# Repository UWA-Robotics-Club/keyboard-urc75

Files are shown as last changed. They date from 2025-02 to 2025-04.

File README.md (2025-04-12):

# Build your own Keyboard - URC 75



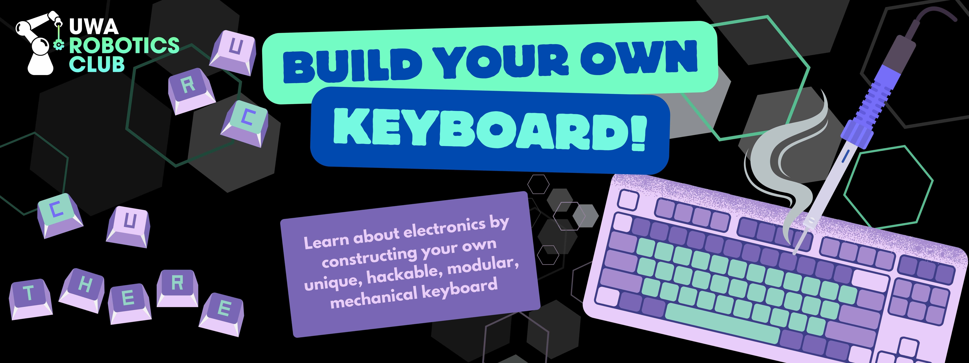
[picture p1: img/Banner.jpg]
Banner


## ⚠️ PSA: Resin printed cases have been identified as a consistant issue. New FDM 3D Printed Cases are currently being investigated, updates will be sent via email. Thank you :) ⚠️
[More about New Cases here](/FDM_Cases/FDM_Cases.md)

## 👀 Overview

This repository contains all files and instructions for the "Build Your Own Keyboard" project created by the UWA Robotics Club. 

This project was designed to be a beginners introduction to building electronics, as well as serving as an interesting product that UWA Robotics Club members have genuine use for, and can use day to day. 

**This project is fully opensource!**<br/>
All files to build your own "URC 75" from scratch, can be found in this respository, from the STEP files, to the schematics of the board, and the QMK firmware. 

# 🛠️ BUILD YOUR OWN! 

We have built a ready-to-go kit! Be sure to grab yours while there is still stock!
<div align = center>

[][Link_Kits]

[][Link_Build_Instructions]

Kit Image
</div>

## ✨ Features
Keyboard Image
- 75% Layout (82 keys)
- USB C Connector
- Hotswap Keyswitch Sockets
- Per Key RGB Lighting
- Acryllic Top Window to see Electronics
- Pudding Style Keycaps
- OLED Display (with Bongo Cat animation)
- Open-source design with complete build files
- Beginner-friendly assembly process
- Customizable firmware

## 🏁 Getting Started / Build Instructions
Full guide on how to assemble and solder your URC 75 Kit. 
- [**Full Guide**](/Build_Instructions/0_Build_Instructions.md)
- [Jump to Soldering](/Build_Instructions/2_Diodes.md)
- [Jump to Mechanical Assembly](/Build_Instructions/6_Heatset_and_Case_Assembly.md)
- [Jump to Firmware Installation](/Build_Instructions/9_Install_Firmware.md)

## 📣 Acknowledgments and Credits

### UWA Robotics Club 
- ⚡️ Prashan Wijesinghe  - Keyboard Electrical and Mechanical Design 
- 👷‍♂️ William Craig - Project Management, Marketing, Administration 
- 💰 UWA Robotics Club - Sponsoring the purchase of parts for kits
### External Credits
- All workshop participants who provided feedback
- QMK Firmware

## License

This project is licensed under the GPL2 

---

Created by UWA Robotics Club - https://uwarobotics.com.au/

[Link_kits]: /Kit_Info.md
[Buy a Kit]: https://img.shields.io/badge/Learn_more_about_our_Kits!-37a779?style=for-the-badge

[Link_Build_Instructions]: /Build_Instructions/0_Build_Instructions.md
[Build Instructions]: https://img.shields.io/badge/View_our_Build_instructions!-37a779?style=for-the-badge

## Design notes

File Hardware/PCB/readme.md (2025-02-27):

# DIY Keyboard Kit - PCB Design

## Repository Contents
This repository contains the following key files for the PCB design:

- **Schematic**: A complete schematic diagram of the keyboard PCB.
- **Bill of Materials (BOM)**: A list of all components required to assemble the PCB.
- **Gerber Files**: PCB manufacturing files, Use these if you want to order more PCB's
- **Altium Files**: A folder containing the neccsary files to edit the project in Altium designer

## Getting Started
To begin using these files for your PCB project:

1. **Download the Repository**: Clone or download the files to your local machine.
2. **Review the Schematic**: Understand the layout and connections.
3. **Order Components**: Use the BOM to gather all necessary parts.
4. **Verify Gerber Files**: Ensure files are correct using a viewer.
5. **Send Gerber Files for Manufacturing**: Choose a PCB manufacturer and provide the Gerber files for production.
6. **Open the project in Altium Designer**: Customize and modify different parts of the keyboard PCB

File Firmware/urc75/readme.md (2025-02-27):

# urc75

A keyboard for the make your own keyboard workshop.

* Keyboard Maintainer: [prash](https://github.com/Quarterpie3141)
* Hardware Supported: prototype-rev4, prototype-rev3, ver1.0 , controllers supported: rp2040, rp2350
* Hardware Availability: depends on workshop

Make example for this keyboard (after setting up your build environment):

    make urc75:default

Flashing example for this keyboard:

    just drag and drop the uf2 file into the RP2 boot drive

See the [build environment setup](https://docs.qmk.fm/#/getting_started_build_tools) and the [make instructions](https://docs.qmk.fm/#/getting_started_make_guide) for more information. Brand new to QMK? Start with our [Complete Newbs Guide](https://docs.qmk.fm/#/newbs).

## Bootloader

Enter the bootloader in 3 ways:

* **Bootmagic reset**: ~~Hold down the key at (0,0) in the matrix (usually the top left key or Escape) and plug in the keyboard~~ Bootmagic is disabled 
* **Physical reset button**: hold down the button on the pcb labeled BTSL, while holding it down press the button labeled RST, or plug the board in
* **Keycode in layout**: Press the key mapped to `QK_BOOT` if it is available - Depends on you own layout

## Customizing
* **To customize layout**: edit the `keymaps/default/keymap.c` file
* **To customize RGB effects**: edit the `info.json` and `config.h` file
* **To customize the OLED Animation**: edit the `urc75.c` file

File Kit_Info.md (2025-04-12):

# Kit Information

## Bill of Materials (URC 75 Kit)
Kit Image
- 1x Resin 3D Printed Top 
- 1x Resin 3d Printed Bottom Case 
- 1x Custom URC75 main circuitboard
- 1x White Pudding style Keycaps Set
- 1x OLED Display
- 1x Stabilisers set ( 1x 6.25u , 3x 1.5u, Rubber gaskets, screws)
- 84x Hotswap Sockets
- 84x Linear Keyswitches
- 84x Through hole Diodes
- 2x 22mm M2 Socket Head Screws
- 2x 20mm M2 Socket Head Screws
- 7x 18mm M2 Socket Head Screws
- 11x 8mm M2 Socket Head Screws
- 33x M2 Heat Set inserts
- 4x M2 Standoffs
- 1x Acryllic window
- 1x Paper Bag Packaging 

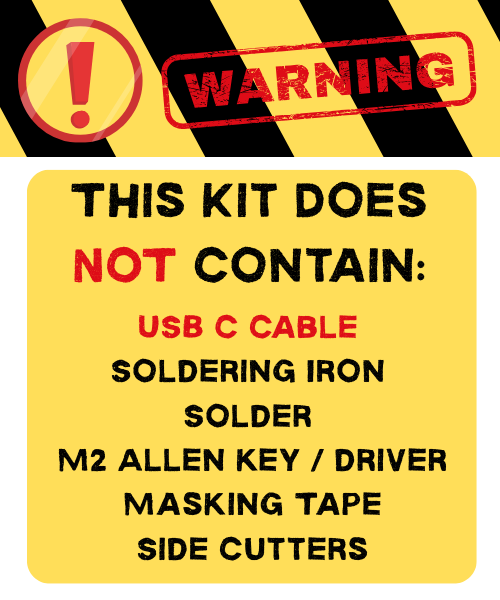
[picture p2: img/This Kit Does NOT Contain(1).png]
Warning Image


### Prerequisites / Tools required
- USB C Cable 
- Soldering iron and solder
- Phillips Screwdriver 
- M2 Allen Key
- Side Cutters
- (Helpful Option) Masking Tape

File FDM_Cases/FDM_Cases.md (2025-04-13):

# FDM Cases 

## TLDR:
Our 3D-printed resin cases for the "Build your own keyboard kit" have several issues including warping, poor tolerances, and discoloration.

As a solution, we're transitioning to FDM-printed cases. I am currently discussing with URC whether costs will be sponsored by the club or paid by customers (approx $5-$10 pp). 

Updates on this issue will be shared via GitHub and email.

Thank you :) - William Craig

# 🚨 Problem
## What has happened?
We contracted an overseas supplier to 3D print resin cases for our "Build your own keyboard kit." Unfortunately, the material properties of the resin have resulted in several significant issues that affect functionality and durability.

### What are the problems with the original cases?
The resin cases have multiple issues:

- Severe warping that affects fit and assembly
- Poor tolerances on heat set insert holes
- The resin responds poorly to heat set inserts, making proper installation difficult
- Discoloration and yellowing with exposure to sunlight

### Why did we buy resin cases? 
Initially, resin cases were chosen for their superior surface finish and aesthetic appeal. We expected them to provide a premium look for the keyboard kits, similar to injection moulding. Unfortunately, the material limitations outweighed these benefits.

## What should I do if I bought a kit already?
If you've already purchased a kit, please hold off on assembling your keyboard if possible. We'll be in touch via email with specific options. If you've already assembled your keyboard, don't worry - we'll ensure you have access to a functional replacement case.

## Do I need to buy a NEW case if I already bought a kit?
I am currently discussing with URC whether costs will be sponsored by the club or paid by customers (approx $5-$10 pp). I would vastly prefer not to charge customers for cases which should be in the kit, as such I will ensure there is some form of compensation for those who have already purchased a kit, if this is the case.

# ✅ Solution
## New FDM Cases 
We're transitioning to FDM (Fused Deposition Modeling) 3D printing technology for the cases.

**I do not just want to REPLACE the keyboard cases, I intend to make them BETTER.**

### Why is FDM better? 
- Can be printed "in house"
- Reduced cost (near 3x cost reduction over resin cases)
- More reliable material properties
    - No Warping 
    - Reliable heat set insert 
    - No discolouration
    - Case dimensions and tolerances can be changed with no cost
- Ability to customise Colour and style PER CUSTOMER 

### New BambuLab P1S Printer with 2 AMS Units
Since ordering the first batch of keyboard kits, I have purchased a Bambulab P1S 3d Printer which I can use to print the replacement cases. 

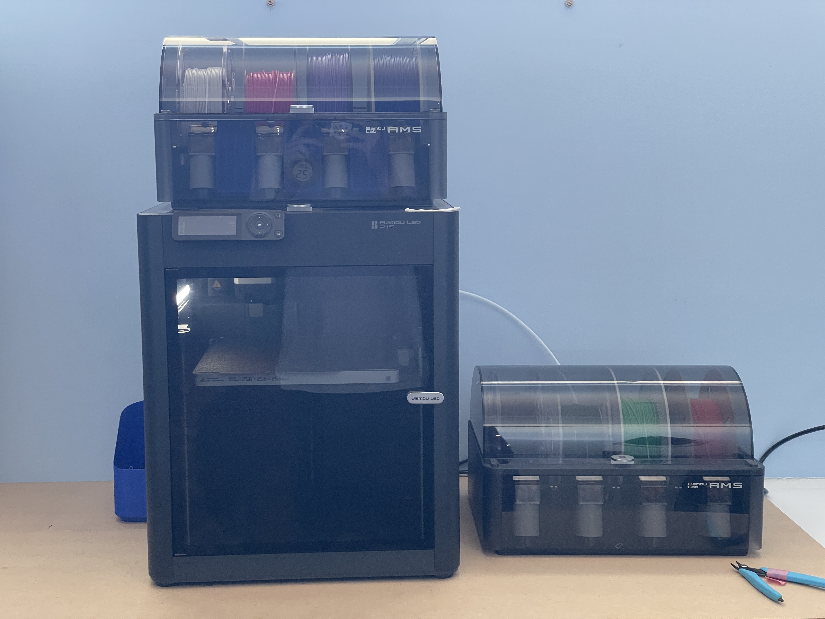
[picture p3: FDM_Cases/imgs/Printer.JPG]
printer


### Multicolour Case Designs
Thanks to the 2 AMS units with my P1S printer, I am able to print the cases with up to 8 colours. These colours are printed into the case, not a paint or sticker. This means that the design will never scratch or peel off.

See a proof of concept design below: 
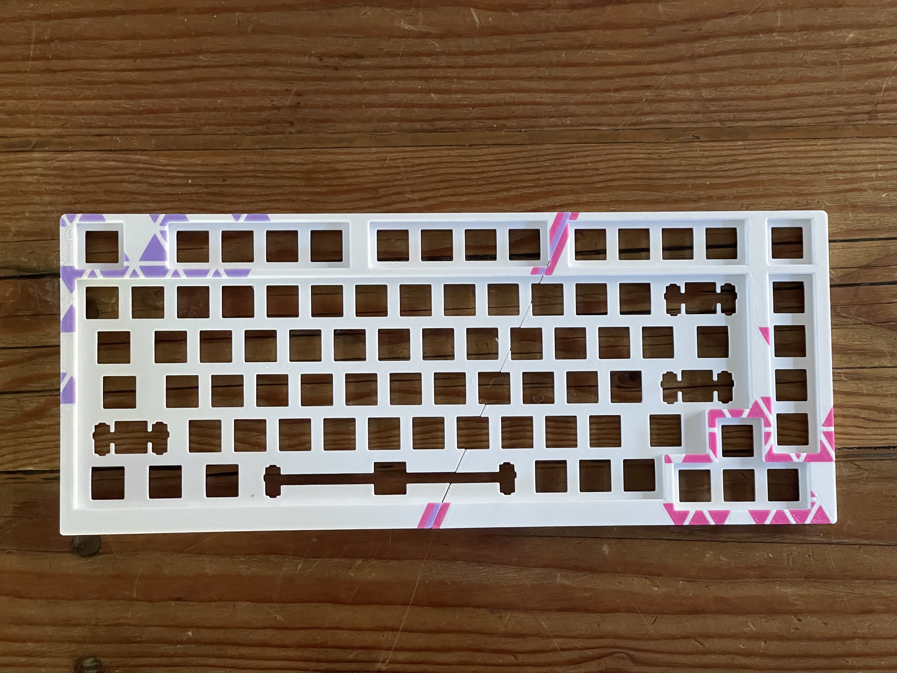
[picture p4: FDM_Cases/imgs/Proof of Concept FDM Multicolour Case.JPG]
case


### Investigating Custom Options
I intend to make several "pre-made" designs which people can pick from.

However the flexibility of FDM allows the opportunity for custom designed cases. I am open to this possibility, however I will focus on "pre-made" designs first, before offering custom options. 

## Final Conclusions
We sincerely apologize for the inconvenience this has caused. I have created and am in the process of implementing a solution which will (with luck) improve the quality, customisability and personality of your URC75 keyboard. 

Thank you for your understanding and patience while this solution gets rolled out. 

:) - William Craig

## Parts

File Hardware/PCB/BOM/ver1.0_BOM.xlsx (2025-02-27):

No. | Quantity | Comment | Designator | Footprint | Value | Manufacturer Part | Manufacturer | Supplier Part | Supplier | Primary Category | Secondary Category | Datasheet | Tolerance | JLCPCB Price
1 | 82 | CHERRY-MX-SW-1U | 0,1,2,3,4,5,6,7,8,9,10,&gt;,&lt;,&quot;,-,;,=,A,B,BACKSPACE,C,CAPS,D,DEL,DOWN,E,ENTER,ESC,F,F1,F2,F3,F4,F5,F6,F7,F8,F9,F10,F11,F12,FN,G,H,I,J,K,L,LALT,LCTRL,LEFT,LSHIFT,LWIN,M,MOD1,MOD2,MOD3,MOD4,N,O,P,Q,R,RALT,RCTRL,RIGHT,RSHIFT,S,SPACE,T,TAB,U,UP,V,W,X,Y,Z,[,\,],~ | CHERRY-MX-PCB-1U |  | MX-SWITCH? |  |  | CHERRY
2 | 2 | TS-1088-AR02016 | BOOTSEL,RST | SW-SMD_L3.9-W3.0-P4.45 |  | TS-1088-AR02016 | XUNPU(讯普) | C720477 | LCSC | Key/Switch | Tactile Switches | https://atta.szlcsc.com/upload/public/pdf/source/20200810/C720475_60D09DD6C54279ADDB2DC25100F1CC11.pdf |  | 0.0377
3 | 2 | 1uF | C16,C17 | C0402 | 1uF | CL05A105KA5NQNC | SAMSUNG(三星) | C52923 | LCSC | Capacitors | Multilayer Ceramic Capacitors MLCC - SMD/SMT | https://atta.szlcsc.com/upload/public/pdf/source/20160218/1457707763339.pdf | ±10% | 0.0025
4 | 8 | 100nF | C18,C23,C25,C26,C27,C28,C31,C32 | C0402 | 100nF | CL05B104KO5NNNC | SAMSUNG(三星) | C1525 | LCSC | Capacitors | Multilayer Ceramic Capacitors MLCC - SMD/SMT | https://atta.szlcsc.com/upload/public/pdf/source/20160218/1457707763339.pdf | ±10% | 0.0011
5 | 2 | 33pF | C19,C20 | C0402 | 33pF | 0402CG330J500NT | FH(风华) | C1562 | LCSC | Capacitors | Multilayer Ceramic Capacitors MLCC - SMD/SMT | https://atta.szlcsc.com/upload/public/pdf/source/20200305/C486355_26A10D38EF8C2A5C37091D0039909270.pdf | ±5% | 0.0011
6 | 2 | 10uF | C21,C22 | C0402 | 10uF | CL05A106MQ5NUNC | SAMSUNG(三星) | C15525 | LCSC | Capacitors | Multilayer Ceramic Capacitors MLCC - SMD/SMT | https://atta.szlcsc.com/upload/public/pdf/source/20220823/2B02EE04F8F211D38A52DCB16EB6BEBA.pdf | ±20% | 0.004
7 | 83 | 1N4148_C14538 | D1,D2,D3,D4,D5,D6,D7,D8,D9,D10,D11,D12,D13,D14,D15,D16,D17,D18,D19,D20,D21,D22,D23,D24,D25,D26,D27,D28,D29,D30,D31,D32,D33,D34,D35,D36,D37,D38,D39,D40,D41,D42,D43,D44,D45,D46,D47,D48,D49,D50,D51,D52,D53,D54,D55,D56,D58,D59,D60,D61,D62,D63,D64,D65,D66,D67,D68,D69,D70,D71,D72,D73,D74,D75,D76,D77,D78,D79,D80,D81,D82,D83,D84 | DO-35_BD2.0-L4.2-P8.20-D0.5-RD |  | 1N4148 | ST(先科) | C14538 | LCSC |  |  |  |  | 0.0081
8 | 1 | 1N4148_C14538 | D57 | DO-35_BD2.0-L4.2-P8.20-D0.5-RD |  | 1N4148 | ST(先科) |  | LCSC
9 | 3 | PZ254V-11-04P | I2C,I2C,I2C | HDR-TH_4P-P2.54-V-M |  | PZ254V-11-04P | XFCN(兴飞) | C2691448 | LCSC | Connectors | Pin Headers | https://atta.szlcsc.com/upload/public/pdf/source/20200309/C492403_F9F19131791D08044AD4F84F8E751A34.pdf |  | 0.0207
10 | 108 | XL-1010RGBC-WS2812B | LED1,LED2,LED3,LED4,LED5,LED6,LED7,LED8,LED9,LED10,LED11,LED12,LED13,LED14,LED15,LED16,LED17,LED18,LED19,LED20,LED21,LED22,LED23,LED24,LED25,LED26,LED27,LED28,LED29,LED30,LED31,LED32,LED33,LED34,LED35,LED36,LED37,LED38,LED39,LED40,LED41,LED42,LED43,LED44,LED45,LED46,LED47,LED48,LED49,LED50,LED51,LED52,LED53,LED54,LED55,LED56,LED57,LED58,LED59,LED60,LED61,LED62,LED63,LED64,LED65,LED66,LED67,LED68,LED69,LED70,LED71,LED72,LED73,LED74,LED75,LED76,LED77,LED78,LED79,LED80,LED81,LED82,LED83,LED84,LED85,LED86,LED87,LED88,LED89,LED90,LED91,LED92,LED93,LED94,LED95,LED96,LED97,LED98,LED99,LED100,LED101,LED102,LED103,LED104,LED105,LED106,LED107,LED108 | LED-SMD_4P-L1.0-W1.0-TL_XL-1010RGBC-WS2812B |  | XL-1010RGBC-WS2812B | XINGLIGHT(成兴光) | C5349953 | LCSC | Optocoupler/LED/Digital Tube/Photoelectric Device | Light Emitting Diodes (LED) | https://atta.szlcsc.com/upload/public/pdf/source/20230111/7F92487BABF607E2EE42D1D66EFE1A21.pdf |  | 0.0566
11 | 6 | 10kΩ | R6,R8,R9,R10,R11,R12 | R0603 | 10kΩ | RC0603FR-0710KL | YAGEO(国巨) | C98220 | LCSC | Resistors | Chip Resistor - Surface Mount | https://atta.szlcsc.com/upload/public/pdf/source/20170522/1495423494387.pdf | ±1% | 0.0011
12 | 2 | 22Ω | R13,R14 | R0402 | 22Ω | 0402WGF220JTCE | UNI-ROYAL(厚声) | C25092 | LCSC | Resistors | Chip Resistor - Surface Mount | https://atta.szlcsc.com/upload/public/pdf/source/20200306/C422600_1E6D84923E4A46A82E41ADD87F860B5C.pdf | ±1% | 0.0005
13 | 3 | 1kΩ | R15,R16,R18 | R0402 | 1kΩ | 0402WGF1001TCE | UNI-ROYAL(厚声) | C11702 | LCSC | Resistors | Chip Resistor - Surface Mount | https://atta.szlcsc.com/upload/public/pdf/source/20200306/C422600_1E6D84923E4A46A82E41ADD87F860B5C.pdf | ±1% | 0.0006
14 | 1 | 10kΩ | R17 | R0402 | 10kΩ | 0402WGF1002TCE | UNI-ROYAL(厚声) | C25744 | LCSC | Resistors | Chip Resistor - Surface Mount | https://atta.szlcsc.com/upload/public/pdf/source/20200306/C422600_1E6D84923E4A46A82E41ADD87F860B5C.pdf | ±1% | 0.0006
15 | 2 | 5.1kΩ | R21,R22 | R0402 | 5.1kΩ | 0402WGF5101TCE | UNI-ROYAL(厚声) | C25905 | LCSC | Resistors | Chip Resistor - Surface Mount | https://atta.szlcsc.com/upload/public/pdf/source/20200306/C422600_1E6D84923E4A46A82E41ADD87F860B5C.pdf | ±1% | 0.0005
16 | 82 | SW-5 | SW1,SW2,SW3,SW4,SW5,SW6,SW7,SW8,SW9,SW10,SW11,SW12,SW13,SW14,SW15,SW16,SW17,SW18,SW19,SW20,SW21,SW22,SW23,SW24,SW25,SW26,SW27,SW28,SW29,SW30,SW31,SW32,SW33,SW34,SW35,SW36,SW37,SW38,SW39,SW40,SW41,SW42,SW43,SW44,SW45,SW46,SW47,SW48,SW49,SW50,SW51,SW52,SW53,SW54,SW55,SW56,SW57,SW58,SW59,SW60,SW61,SW62,SW63,SW64,SW65,SW66,SW67,SW68,SW69,SW70,SW71,SW72,SW73,SW74,SW75,SW76,SW77,SW78,SW79,SW80,SW81,SW82 | SW-SMD_KAILH-SOCKET_C9900019772 |  | SW-5 |  | C9900019772 | LCSC |  |  |  |  | 0.0365
17 | 1 | RP2040 | U1 | LQFN-56_L7.0-W7.0-P0.4-EP |  | RP2040 | Raspberry Pi(树莓派) | C2040 | LCSC | Single Chip Microcomputer/Microcontroller | Microcontroller Units (MCUs/MPUs/SOCs) | https://atta.szlcsc.com/upload/public/pdf/source/20210621/C2040_96F425825606B7957D87DD32E2512CA9.pdf |  | 1.002
18 | 1 | AMS1117-3.3 | U2 | SOT-223-3_L6.5-W3.4-P2.30-LS7.0-BR |  | AMS1117-3.3 | AMS | C6186 | LCSC | Power Supply Chip | Linear Voltage Regulators (LDO) | https://atta.szlcsc.com/upload/public/pdf/source/20180727/C6186_7A095716F0823C02F1997A905E26C086.pdf |  | 0.1478
19 | 1 | W25Q128JVSIQ | U3 | SOIC-8_L5.3-W5.3-P1.27-LS8.0-BL |  | W25Q128JVSIQ | WINBOND(华邦) | C97521 | LCSC | Memory | NOR FLASH | https://atta.szlcsc.com/upload/public/pdf/source/20170316/1489627409956.pdf |  | 0.555
20 | 1 | GT-USB-7010ASV | U4 | USB-C-SMD_G-SWITCH_GT-USB-7010ASV |  | GT-USB-7010ASV | G-Switch(品赞) | C2988369 | LCSC | Connectors | USB Connectors | https://atta.szlcsc.com/upload/public/pdf/source/20230327/DF227B64686AC8FA0AD1775797F2C3F1.pdf |  | 0.078
21 | 1 | 12MHz | X1 | OSC-SMD_4P-L3.2-W2.5-BL | 12MHz | X322512MSB4SI | YXC(扬兴晶振) | C9002 | LCSC | Crystal Oscillator/Oscillator/Resonator | Crystals | https://atta.szlcsc.com/upload/public/pdf/source/20240329/19D5F850207469550BEB00D7DFEDBC7A.pdf |  | 0.0657

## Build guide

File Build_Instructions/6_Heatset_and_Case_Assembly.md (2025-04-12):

## Build your own Keyboard - URC 75

# Heat sets and Case assembly

In this section, we will show you how to heat set your threaded inserts into your case and then assemble your case together.

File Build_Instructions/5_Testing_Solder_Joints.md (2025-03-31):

## Build your own Keyboard - URC 75

# 5. Testing the Solder Joints

In this section, we will show you how to test all your connections and ensure that your board is working correctly

# Loading the Firmware 


  Find a USB C Cable to connect your Board to your computer <br/>

### NOTE: this kit DOES NOT include a USB C Cable 


  Plug your USB Cable into your computer. 
  
  HOLD THE "BOOTSEL" Button down while plugging the board into your computer <br/>

### NOTE: if you do not hold down the BOOTSEL button the following will not work.


  Your Board should show up on your computer as USB Drive called RPI-RP2 <br/>

## [Download the firmware from our repo here](/Firmware/urc75/urc75_FIRMWARE.uf2)

The firmware you downloaded should be a .uf2 filetype. 

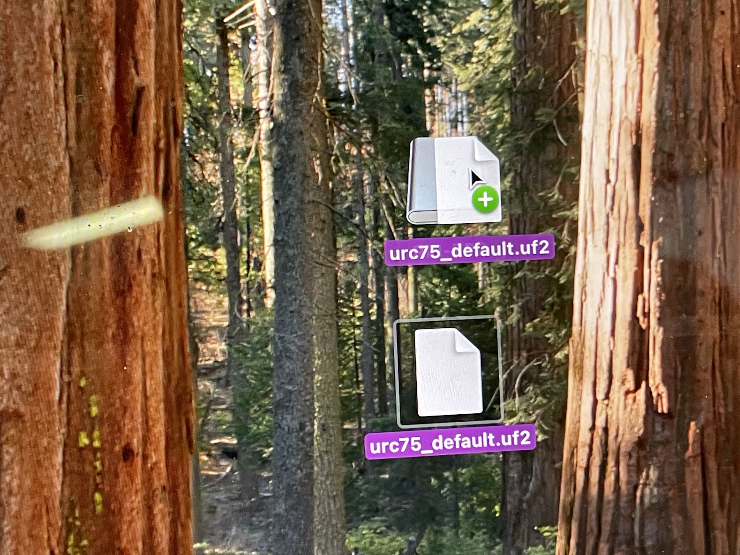
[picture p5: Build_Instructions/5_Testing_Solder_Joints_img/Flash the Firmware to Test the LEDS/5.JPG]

  Copy the Firmware to your board by transferring the .uf2 file to the USB Drive called RPI-RP2 <br/>

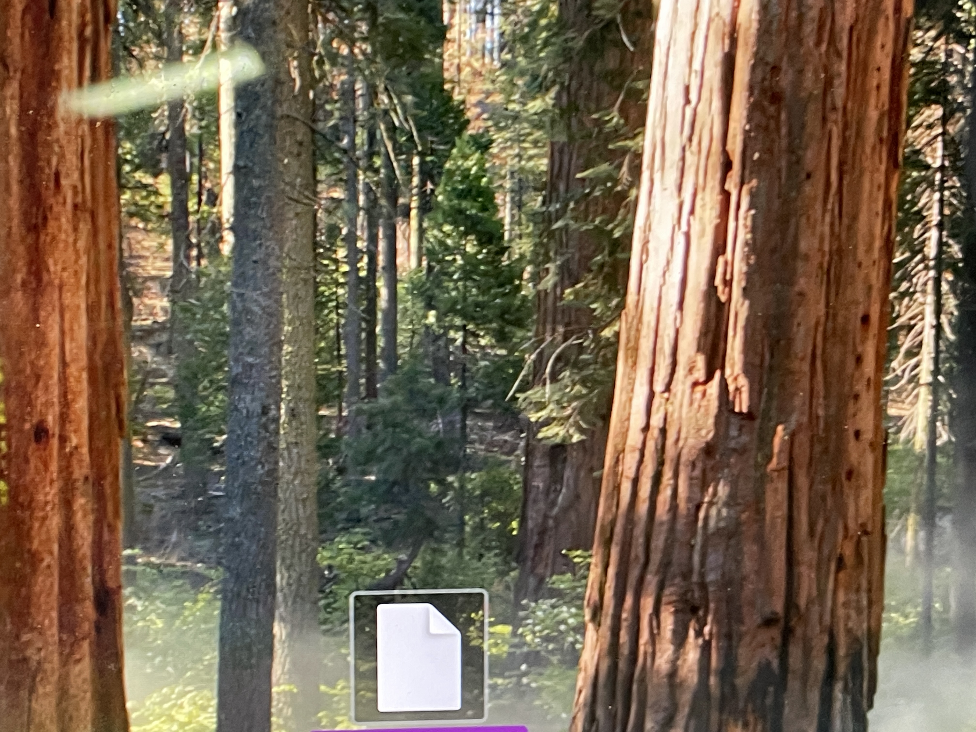
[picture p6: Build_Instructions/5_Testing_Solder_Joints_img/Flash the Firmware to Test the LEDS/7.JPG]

  ### NOTE: The Board should SELF - EJECT <br/>

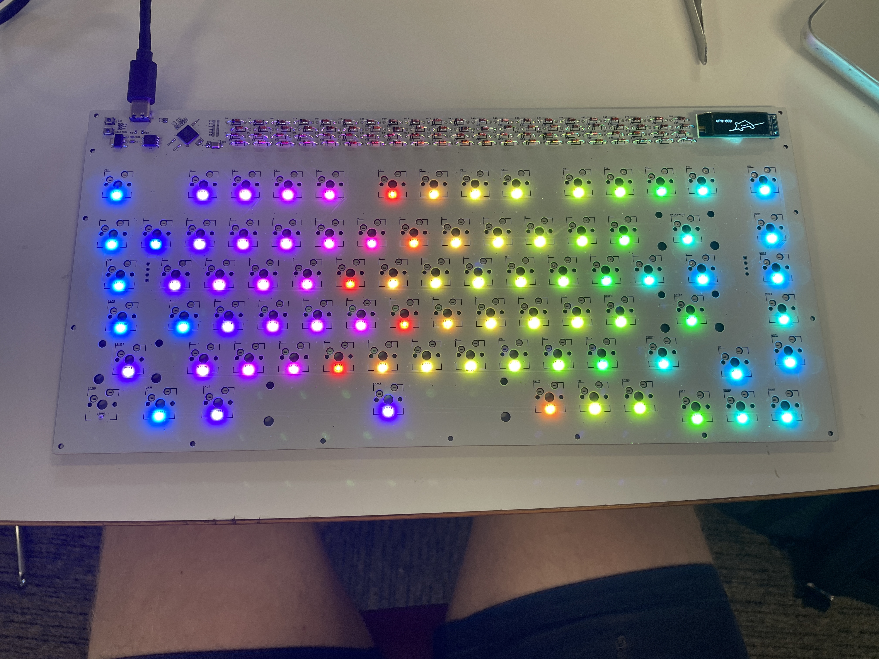
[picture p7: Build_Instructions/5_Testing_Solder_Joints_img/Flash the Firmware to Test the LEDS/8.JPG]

 Your Board should Light Up as shown here!  <br/>

# Testing all the keys
In this section we will short all of the keys to ensure that both the sockets and the diodes which you soldered are working correctly for every key

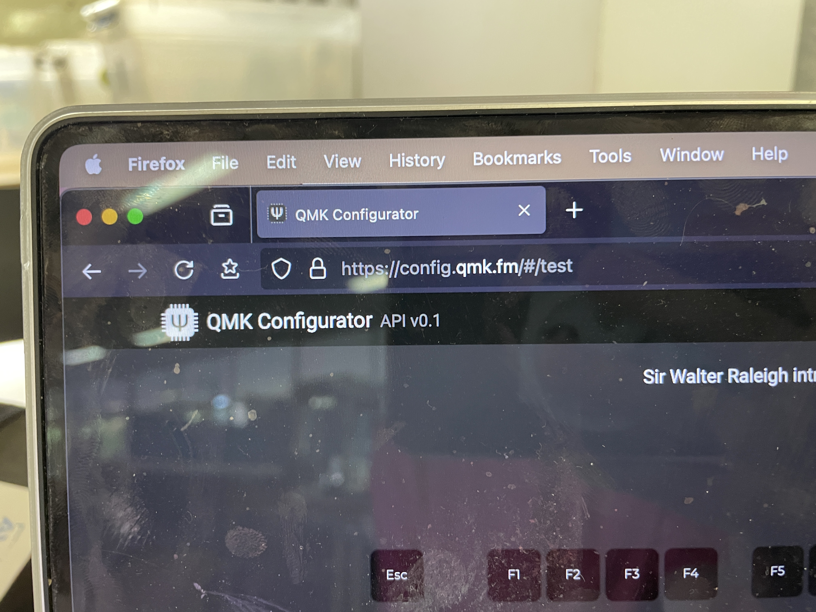
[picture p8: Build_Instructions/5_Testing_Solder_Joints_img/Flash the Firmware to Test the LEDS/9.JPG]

Go to a Keyboard testing site such as the [one hosted by QMK Firmware](https://config.qmk.fm/#/test)  <br/>

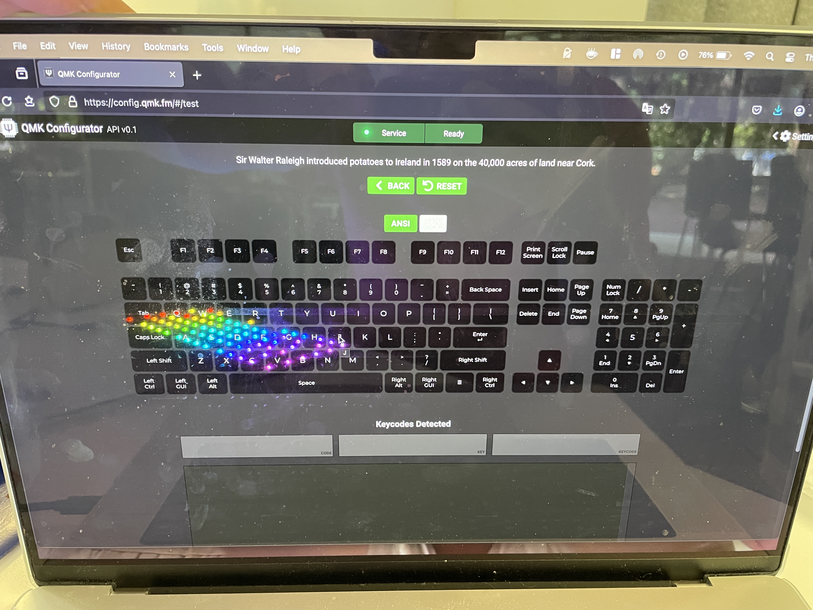
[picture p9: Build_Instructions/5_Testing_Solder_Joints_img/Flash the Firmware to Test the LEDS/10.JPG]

 The testing site should look like this   <br/>

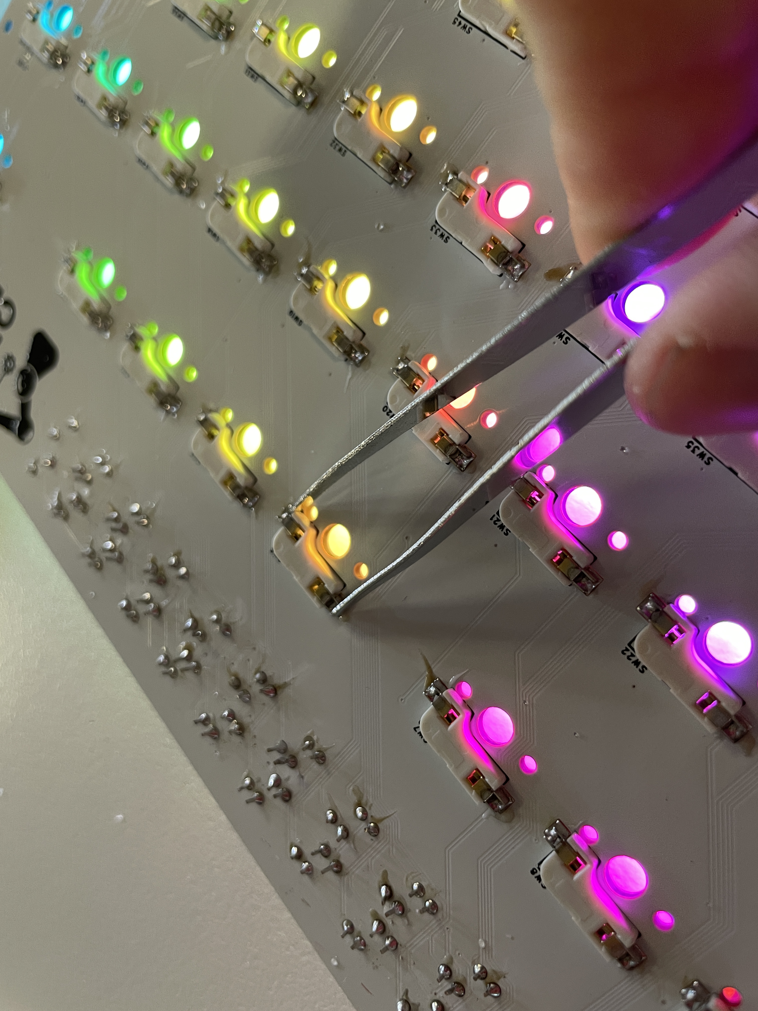
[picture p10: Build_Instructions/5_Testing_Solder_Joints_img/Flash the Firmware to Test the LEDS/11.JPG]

 Turn your board over and use something conductive to bridge the solderjoints on the socket for each key. Your kit comes with a paperclip , which is perfect for this, else you can use tweezers, solder or something else.   
 
 Doing this "simulates" a key stroke from a switch, and the electrical current passes through both the Diode and the socket. If there is any problems with the solder joints on those components, it will not register a keystroke to the computer.
   <br/>

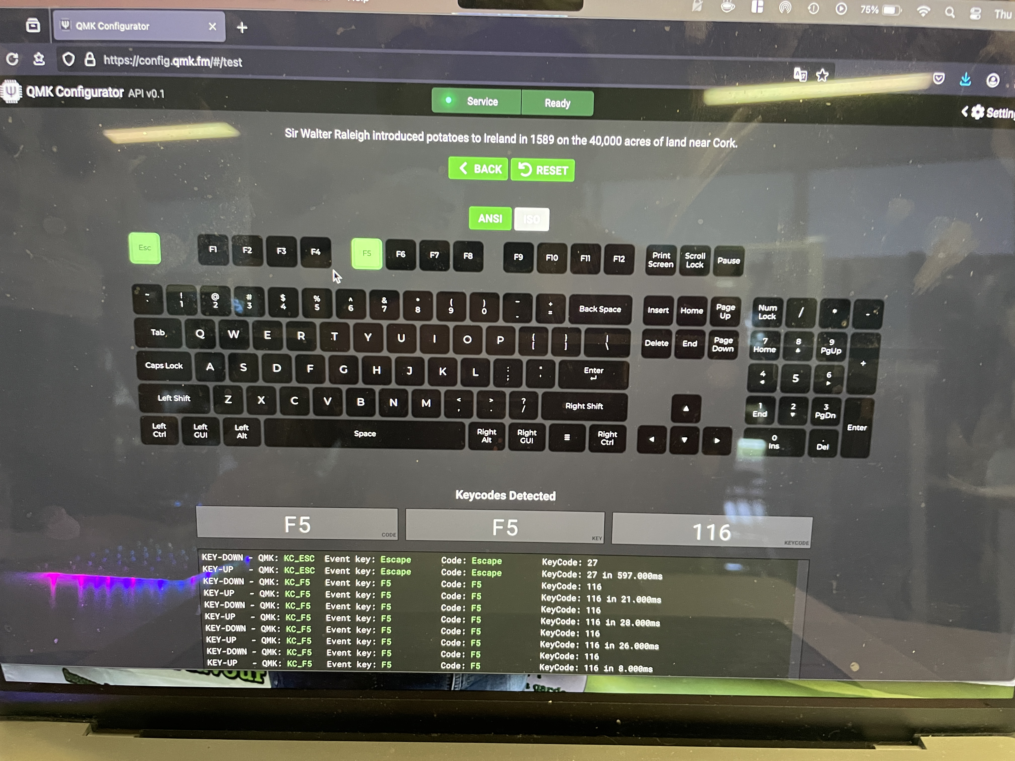
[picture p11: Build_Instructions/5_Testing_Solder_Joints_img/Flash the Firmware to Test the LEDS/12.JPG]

After touching the solder joints for a key, it should show as green on the testing site   <br/>

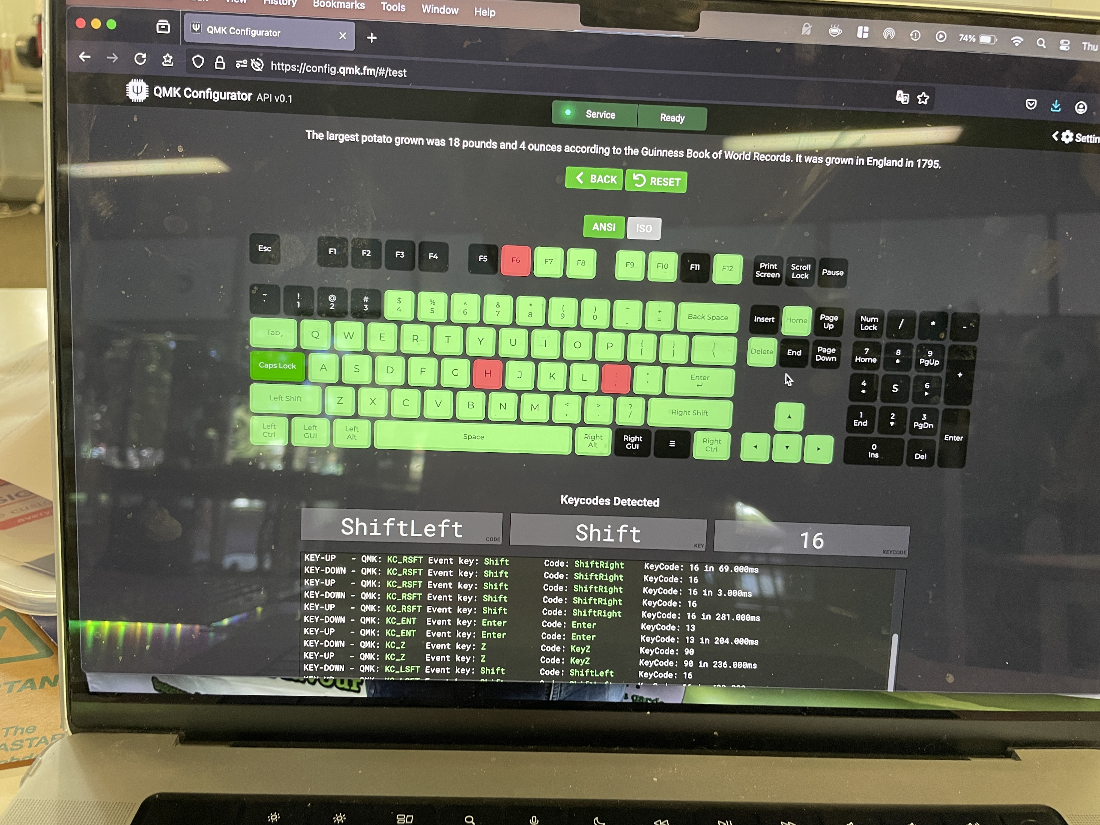
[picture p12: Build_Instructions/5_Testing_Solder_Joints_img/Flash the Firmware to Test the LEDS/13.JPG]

If any keys display as RED, this is ok, it means that the key has been detected by the computer but that there is some chatter on that signal. 

This could just be because we are shorting the signalwire with a paperclip, but if it is a genuine problem, then you can reflow the solder joints on the Diode (top of the board) and the switch socket <br/>

When you have tested all the solder joints, your display should have the following keys be lit up is either green or red: 
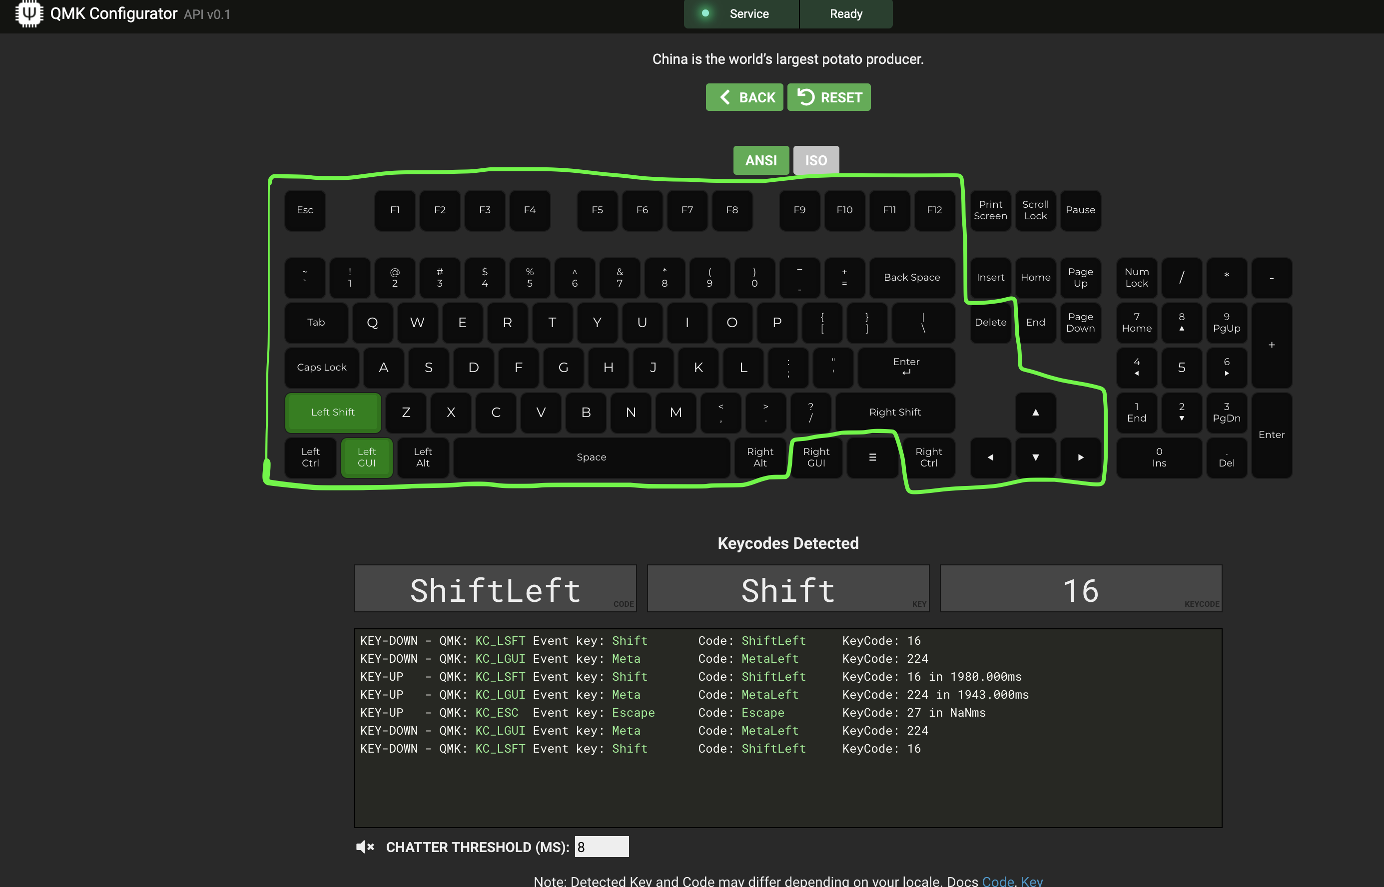
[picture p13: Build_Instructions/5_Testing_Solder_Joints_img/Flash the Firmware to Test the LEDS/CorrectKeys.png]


You should notice that there are some keys on the Right side of the board (when looking from the front) which do not do anything when they are pressed, this is because we have mapped these keys to MEDIA functions by default. 

In the below image the mapping should be: 
Red = DELETE, GREEN = Volume Up, BLUE = Volume Down, Orange = Next song, Purple = Play/Pause



In order to test these keys, you may need to open a music app like Spotify to test the "Next song" and "Play/pause " functions. If the song is successfully changed, and the play pause functionality is seen, then the electrical connections to these switches are successful.

# Well Done ! You have tested all your solder joints for your keyboard! 

Next you will Assemble the Case!

# [Go to next Section](/Build_Instructions/6_Heatset_and_Case_Assembly.md)

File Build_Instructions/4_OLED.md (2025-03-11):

## Build your own Keyboard - URC 75

# 4. OLED

In this section, we will show you solder the OLED display to your board

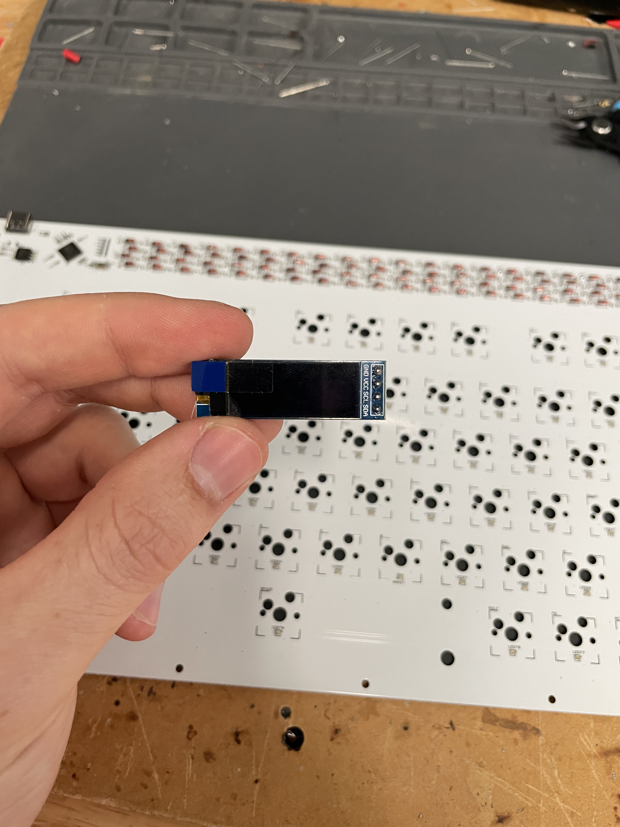
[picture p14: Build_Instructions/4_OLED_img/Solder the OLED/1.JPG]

  Go and retreive the OLED Display from your kit <br/>

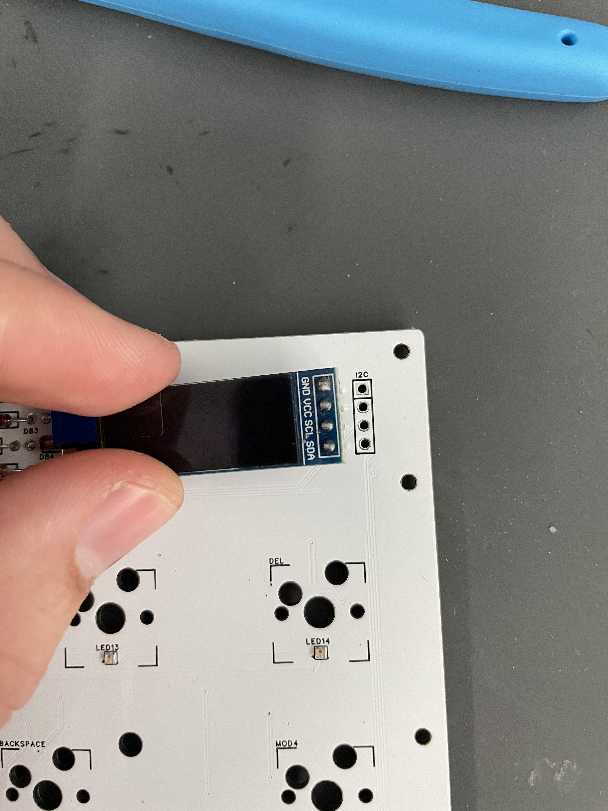
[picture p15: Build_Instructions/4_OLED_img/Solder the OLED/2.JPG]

  The OLED display is placed on the TOP side of your main board, and then soldered from behind. <br/>

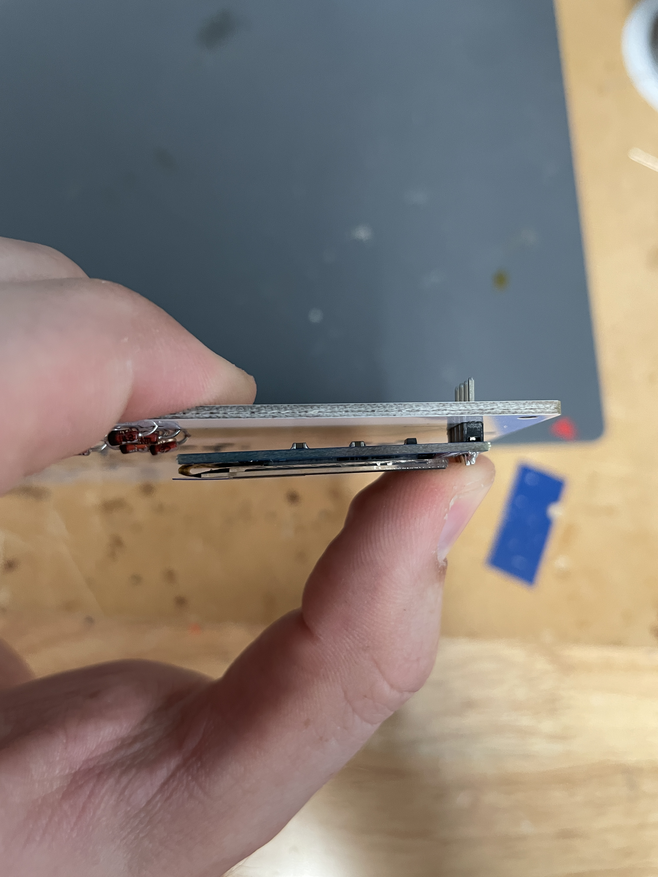
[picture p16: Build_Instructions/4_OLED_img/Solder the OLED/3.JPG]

  The OLED's pins disable it from sitting flat on the surface of the PCB, you can decide if you would like your OLED to hover parrallel to the PCB or if you would like it to slope down against the PCB. 
  
  There is no functional difference between these two options, its just aethestics and personal taste. <br/>

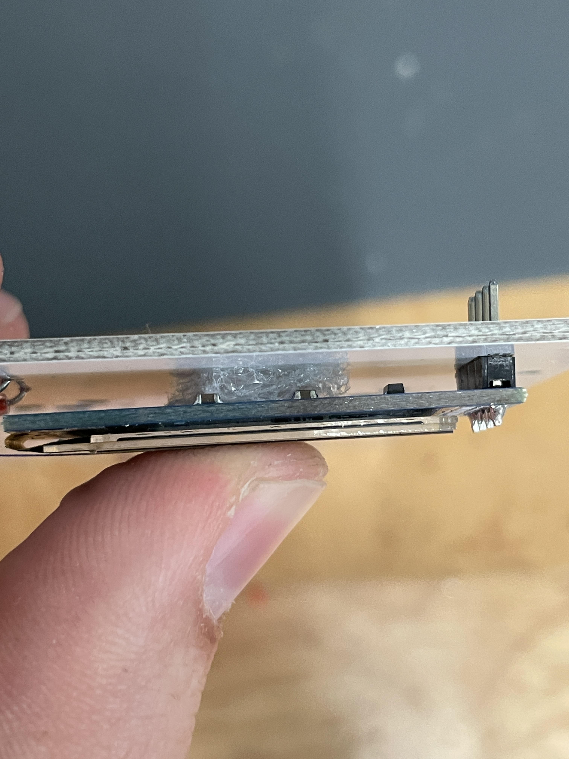
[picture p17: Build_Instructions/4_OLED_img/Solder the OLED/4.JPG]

  I prefer the "parrallel" style, so I have put a piece of foam on the underside of my OLED as a spacer while I am soldering <br/>

### TIP : Not shown in the photos, but a good idea would be to tape the display in place before soldering so it can not move. Similar to how you did the 

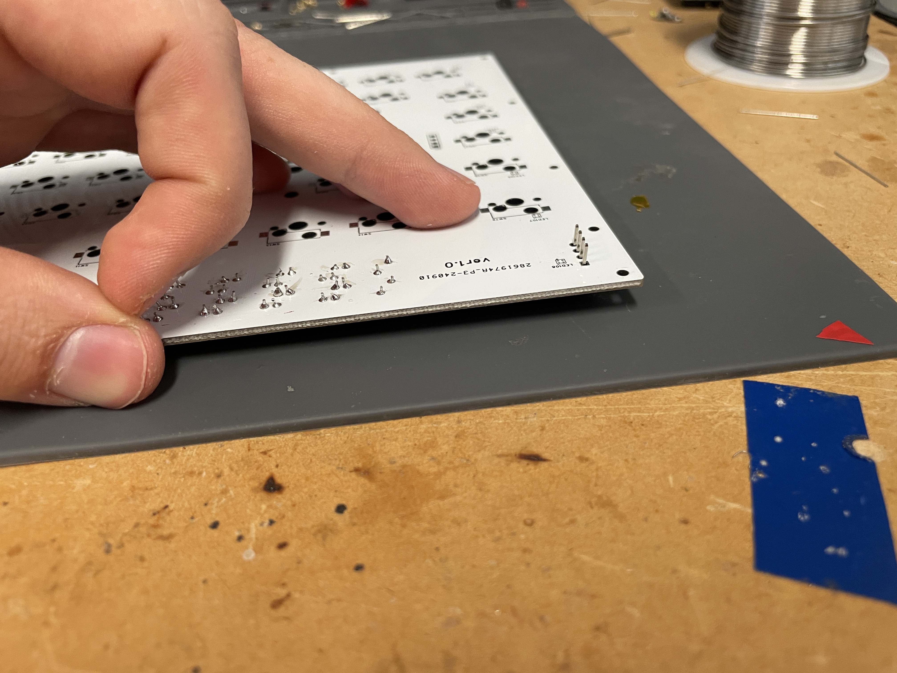
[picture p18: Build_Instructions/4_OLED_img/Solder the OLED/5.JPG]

  Turn your board over and solder just the top and bottom pins<br/>

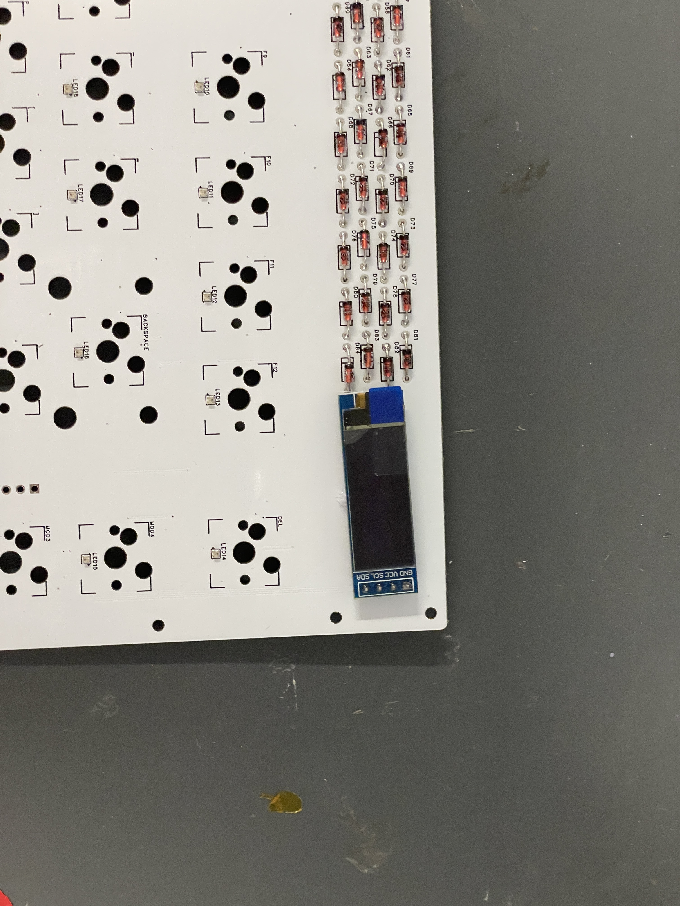
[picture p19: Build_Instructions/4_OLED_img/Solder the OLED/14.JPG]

  Turn your board over to the front and ensure that the display is straight, this photo shows a display that is slightly tilted down<br/>

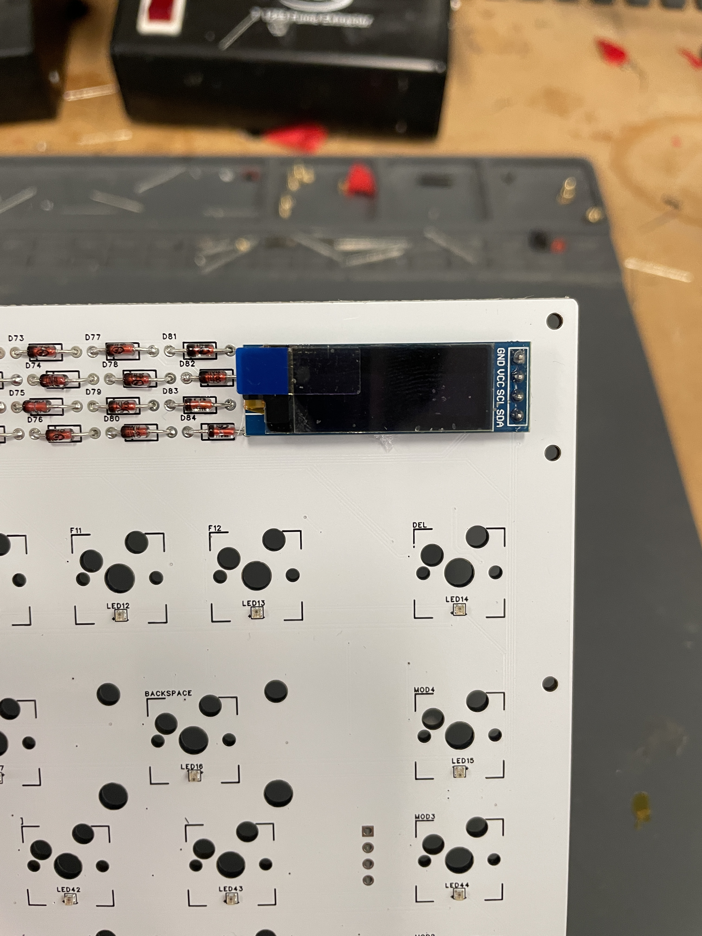
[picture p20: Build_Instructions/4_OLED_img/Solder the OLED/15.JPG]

  Since you only soldered the top and bottom pins, You can remelt your solder joints and turn the OLED so that it is straight.<br/>

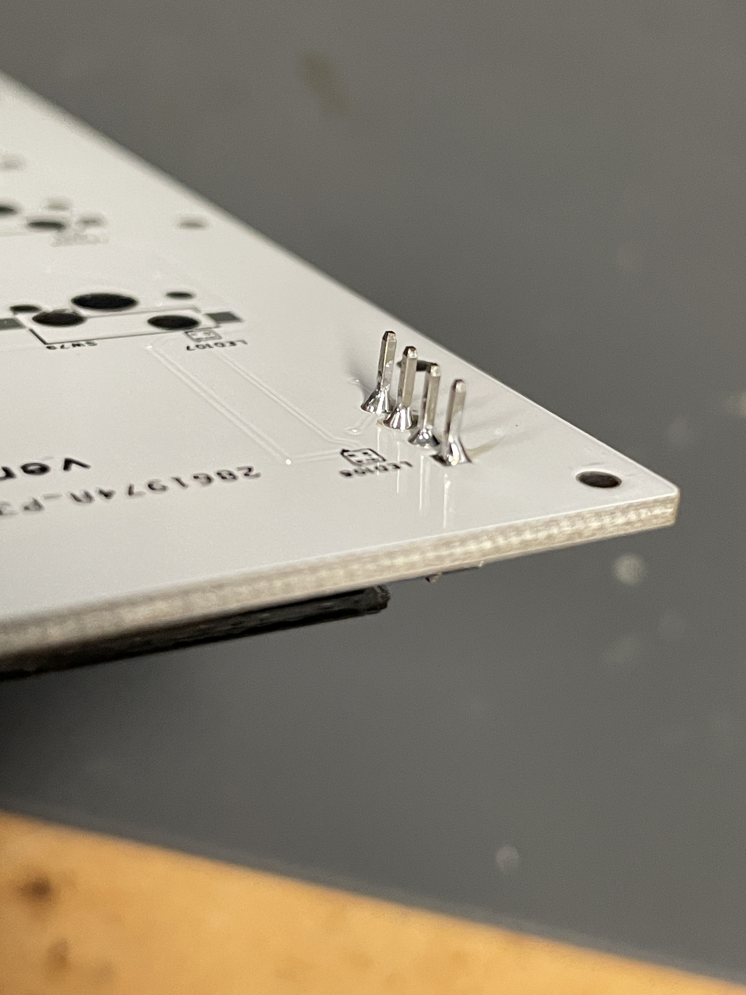
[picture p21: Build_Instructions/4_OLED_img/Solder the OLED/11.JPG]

  Solder the remaining 2 pins.<br/>

# Well Done ! You have soldered the OLED Display!

[Go to the Next Section](/Build_Instructions/5_Testing_Solder_Joints.md)

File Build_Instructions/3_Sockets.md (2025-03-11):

## Build your own Keyboard - URC 75

# 3. Sockets

In this section, we will show you how to put your sockets onto your board and solder them in place 

# Preparing the sockets 

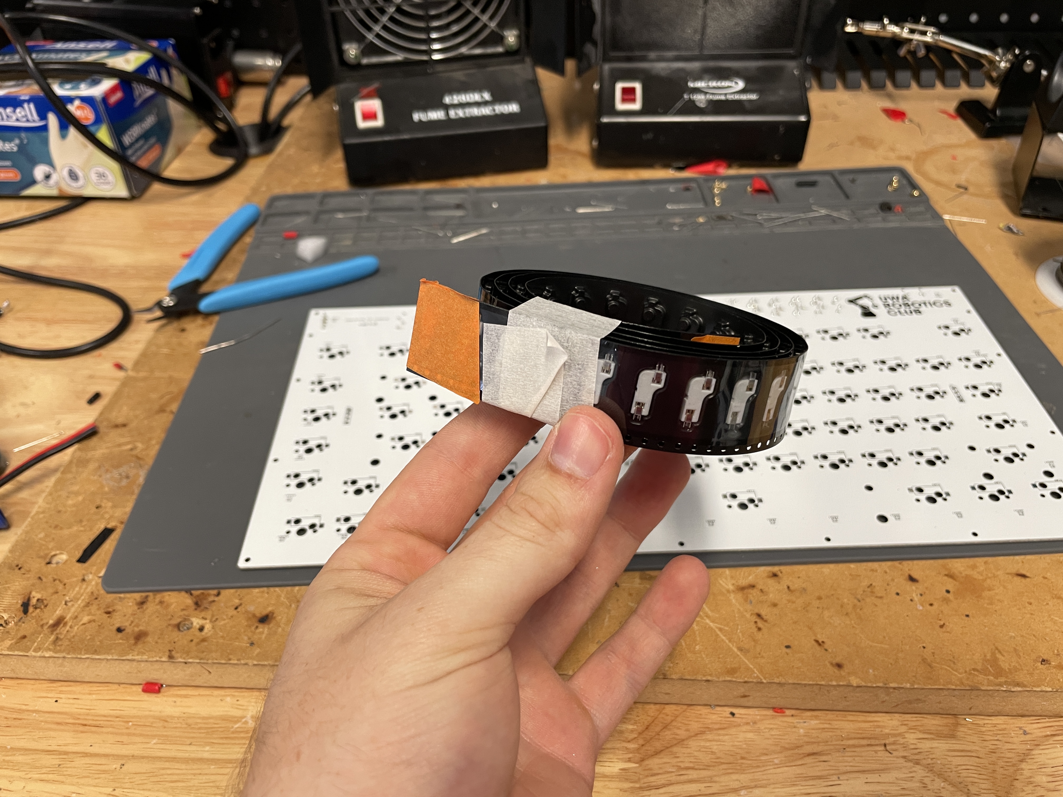
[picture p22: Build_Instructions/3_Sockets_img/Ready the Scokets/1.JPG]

  Get your reel of Sockets from your kit <br/>

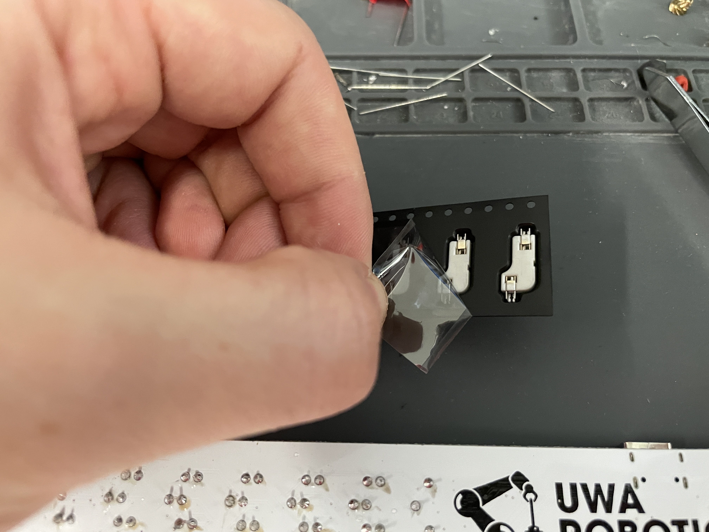
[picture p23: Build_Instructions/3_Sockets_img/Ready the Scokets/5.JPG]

The Sockets are contained in a Reel of Tape which has a plastic film on the top to stop the parts from falling out. 

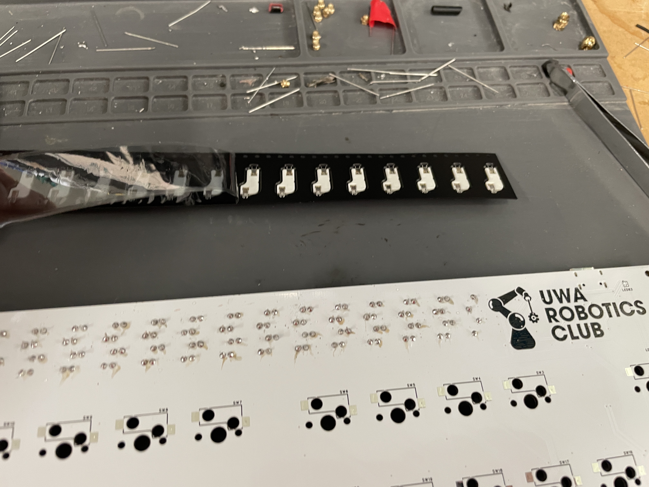
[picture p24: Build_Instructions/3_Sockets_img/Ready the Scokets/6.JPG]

   <br/>
### Carefully remove ONLY the first 5-10 sockets worth of plastic film, NOT THE WHOLE THING 
If you remove all of the plastic film, then all of your sockets will be loose, and you will likely loose them or get them mixed up with another person. 

<br/>

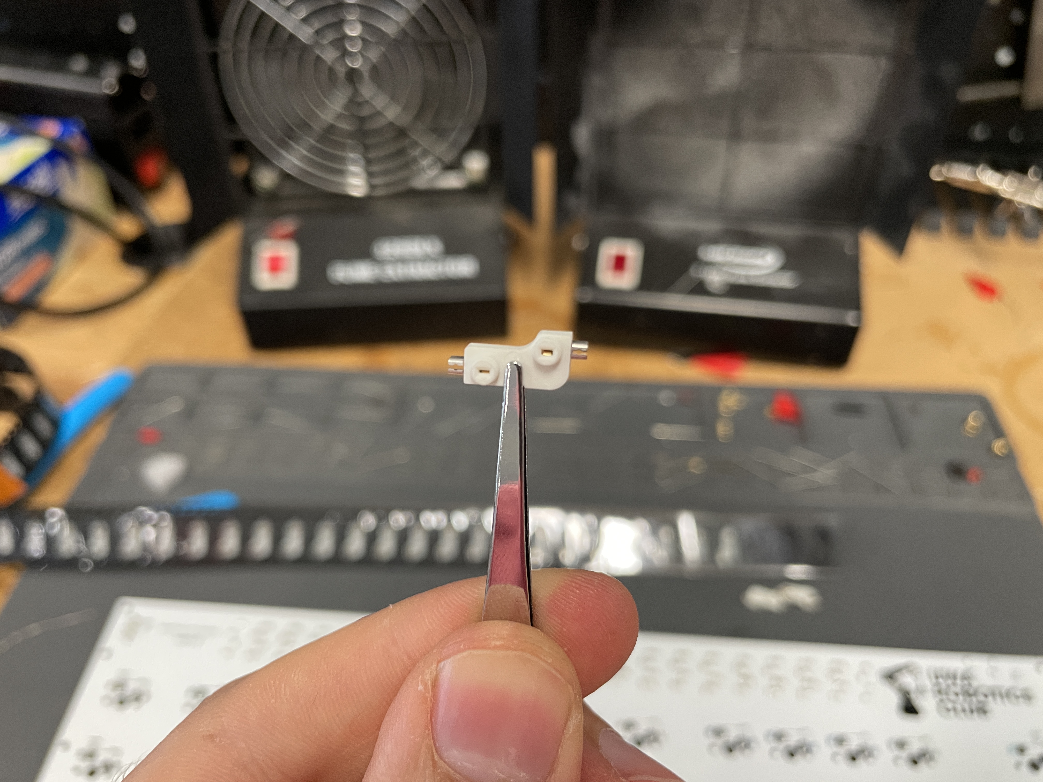
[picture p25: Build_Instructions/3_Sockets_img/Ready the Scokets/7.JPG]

  This is what the sockets look like, on this side there is two circular protrusions which have visible sockets in them. You can also see that it is clearly a soft L shape.  <br/>

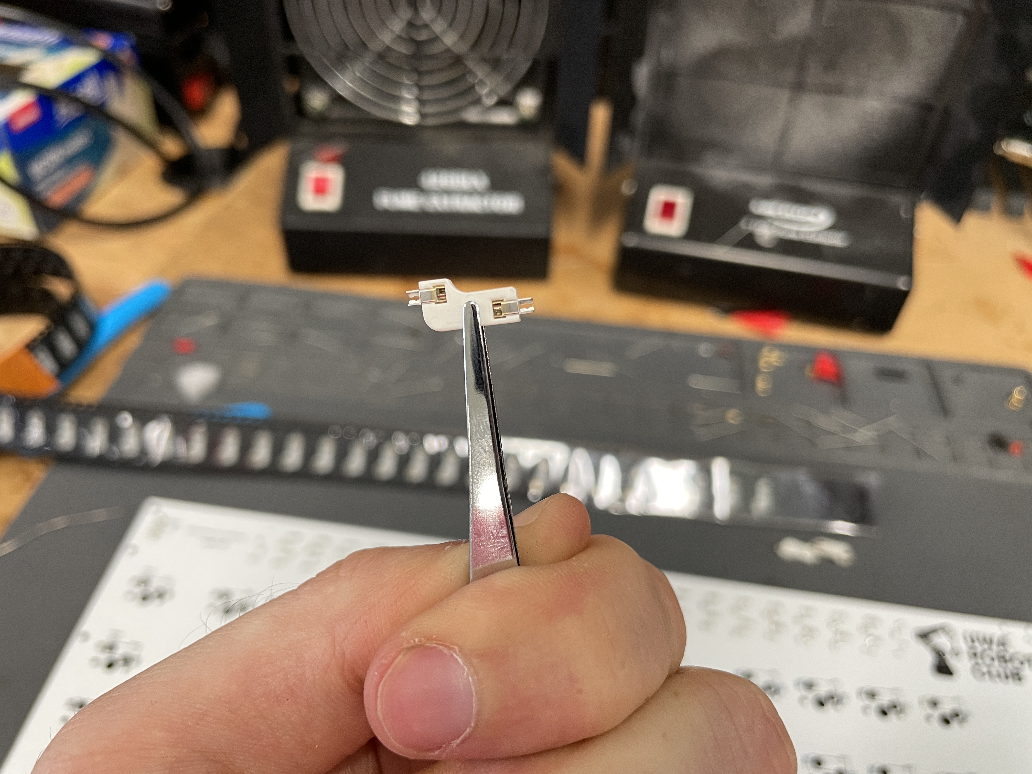
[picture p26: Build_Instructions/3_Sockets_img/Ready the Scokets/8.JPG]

This is the otherside of the socket, you can see that this side is flat, and has visible metal parts <br/>

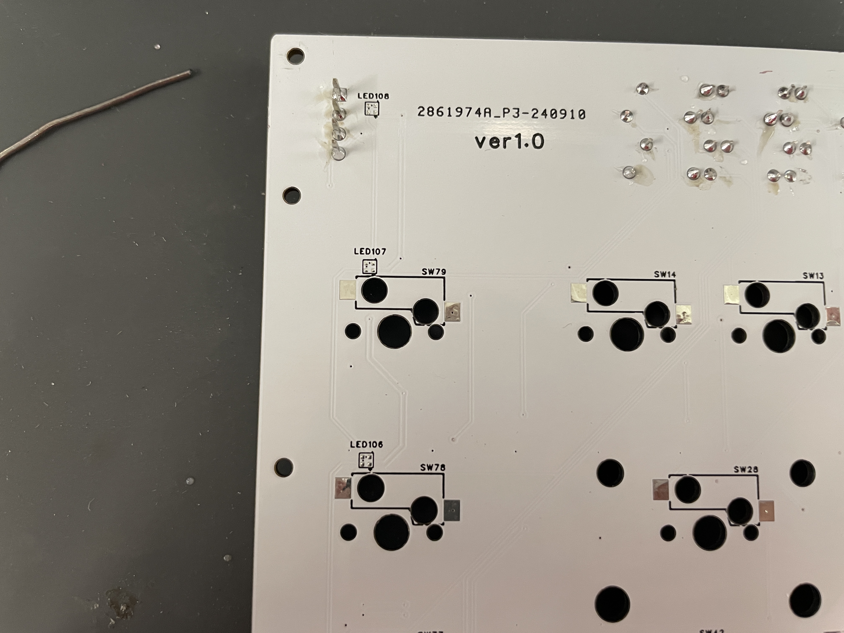
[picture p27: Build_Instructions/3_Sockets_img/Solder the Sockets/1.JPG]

Get your board from your kit and have a look at the back of it, you will see the outline of where you will place your sockets.  <br/>

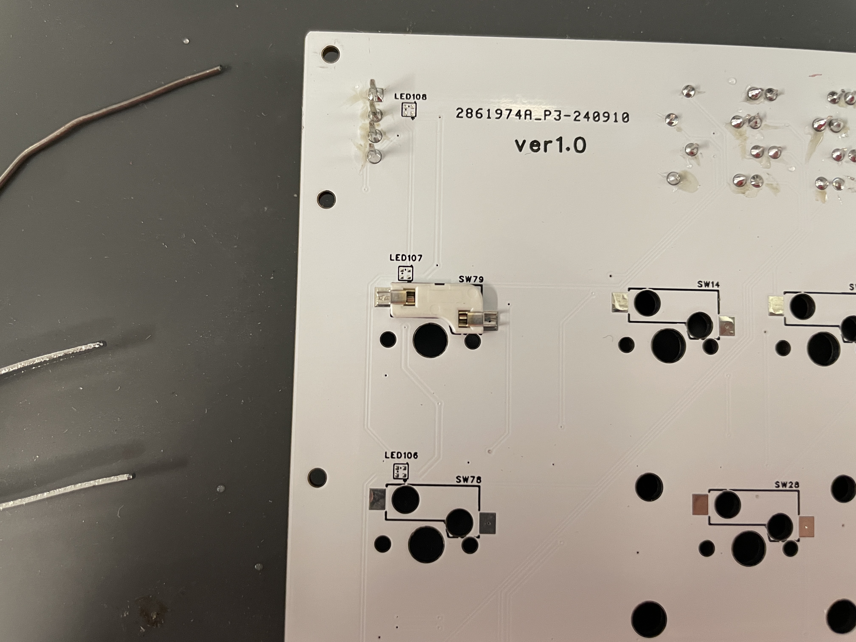
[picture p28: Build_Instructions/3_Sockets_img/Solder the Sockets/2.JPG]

You will need to place your so that it aligns with the outline. 
 <br/>

 ### CAUTION! : The sockets can be physically installed backwards, pleas ensure that your sockets are matching the orientation shown on the outline

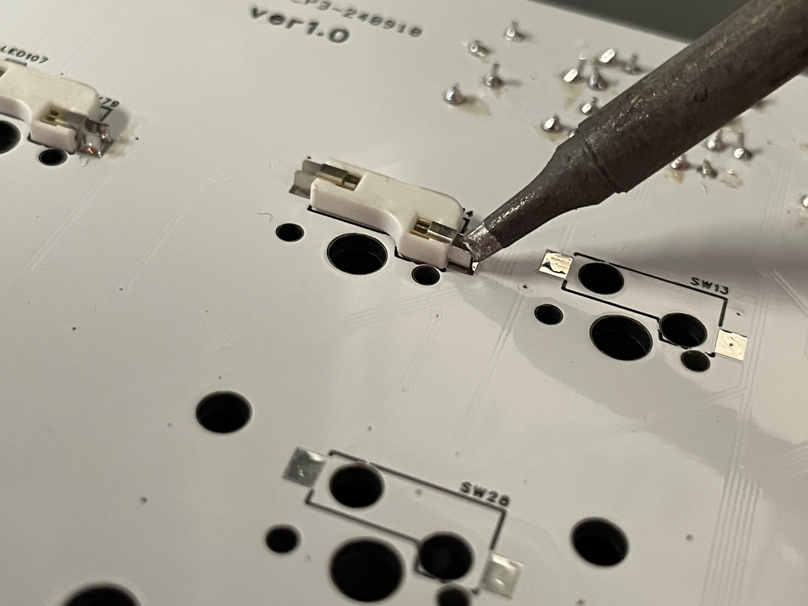
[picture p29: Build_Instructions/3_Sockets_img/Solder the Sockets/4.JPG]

The sockets have a metal contact "wings" which lay on the board and are soldered down, this is a SMD (Surface mount device) part which means that you place the part and solder it on the same side, rather than poking it through the board( like the diodes)

When placed on the PCB you will notice that the socket's "wings" are a "U" shape. To solder the "wings" of the sockets down to the board, place your soldering iron inside the channel and heat it up for around 4-5 seconds, then add your solder into the 'U'.<br/>

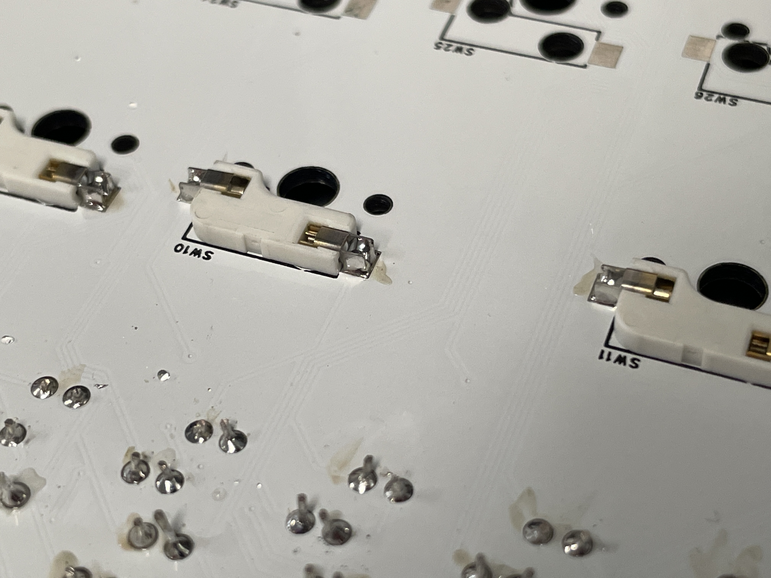
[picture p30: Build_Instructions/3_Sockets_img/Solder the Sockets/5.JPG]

The solder joint should look like this<br/>

### TIP : In my experience the best way to solder these sockets is to solder one "wing", and then wait for it to cool, then try and wiggle the socket, if it DOES NOT move, you have likely soldered correctly and can solder the other side. IF it DOES move, your solder joint has not made connection to the board, remelt the solder and it may wick to the PCB.

### CAUTION! : The "Wings" are made of metal and the rest of the socket is made of a plastic. If you overheat your socket, you can melt the plastic part of your socket.
### CAUTION! : The "Wings" are made of metal IF YOU TOUCH IT BEFORE IT COOLS DOWN, IT WILL BURN YOU


Solder all of your sockets<br/>

# Well Done ! You have soldered all of the sockets!

[Go to the next section](/Build_Instructions/4_OLED.md)

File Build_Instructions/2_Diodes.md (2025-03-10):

## Build your own Keyboard - URC 75

# 2. Diodes 

In this section, we will show you how to bend your diodes with a 3d printed bending jig, place them all in place on your board, and solder them.

# Bending the Diodes 

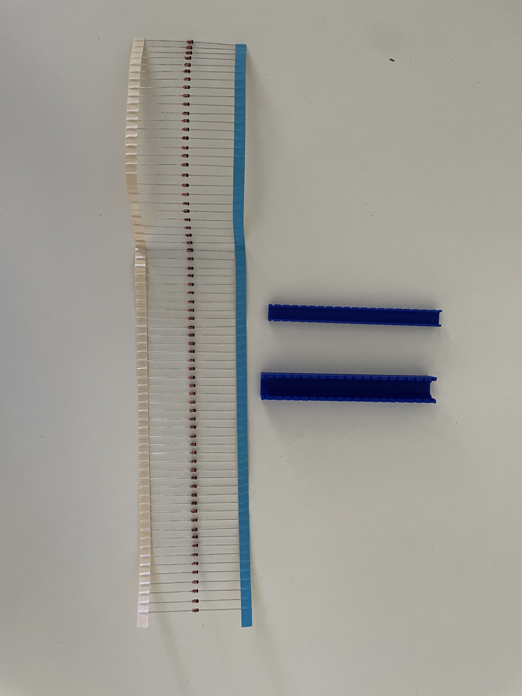
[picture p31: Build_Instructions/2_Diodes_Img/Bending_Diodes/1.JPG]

  Get your Ribbon of diodes from your hardware kit , and request a Diode bender jig <br/>

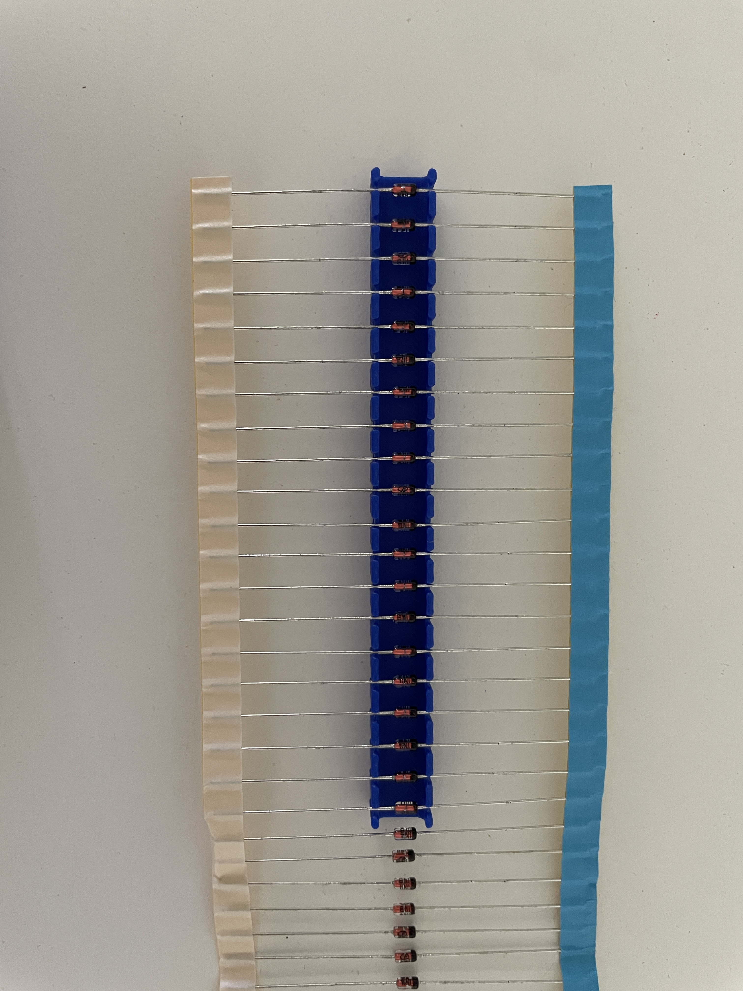
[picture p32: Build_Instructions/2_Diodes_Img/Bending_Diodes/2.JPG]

  Put your diodes in the center of the SMALLER piece of the diode jig , **ensure that the diodes are centered to ensure the diode is centered when placed on the board<br/>

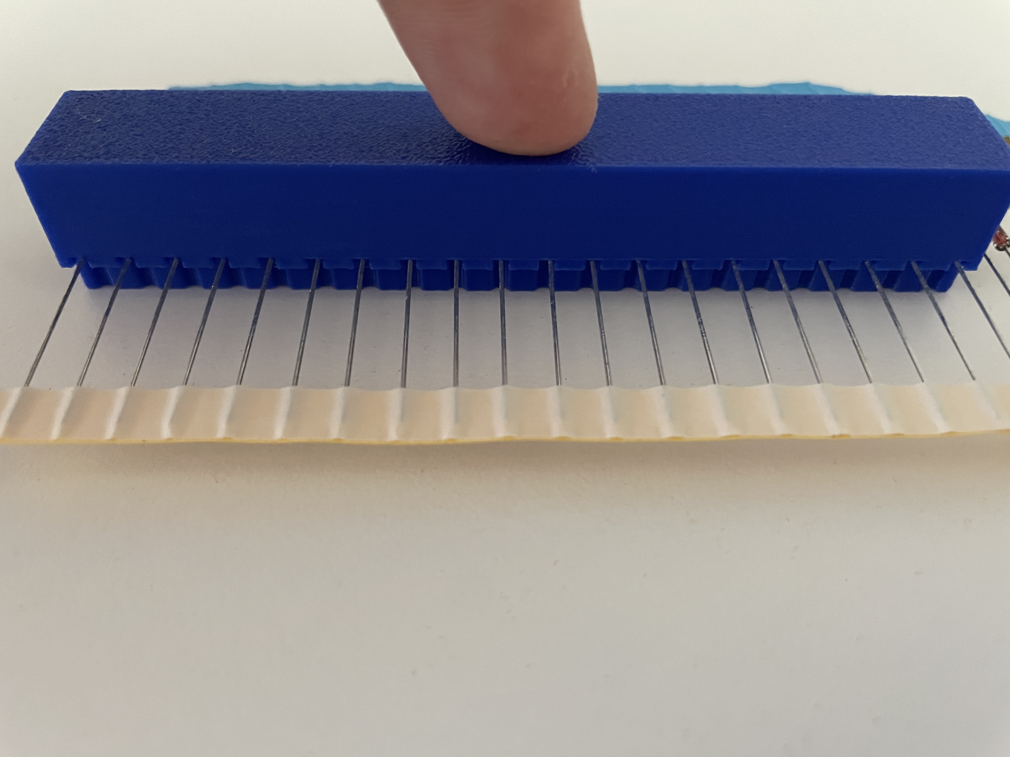
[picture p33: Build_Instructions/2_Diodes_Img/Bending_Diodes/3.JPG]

  Put the LARGER piece on top and ensure that the notches are lined up with the diode legs  <br/>

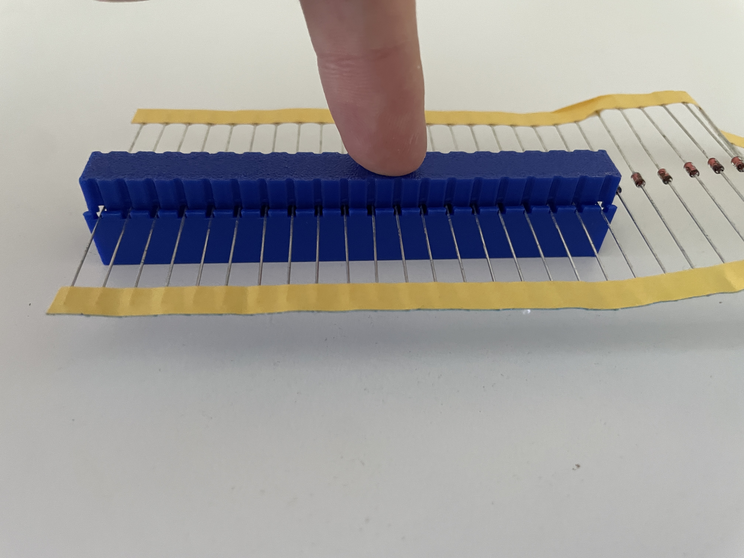
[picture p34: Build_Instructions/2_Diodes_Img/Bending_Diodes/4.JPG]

  Carefully Flip the assembly around so the LARGER piece is on the bottom  <br/>

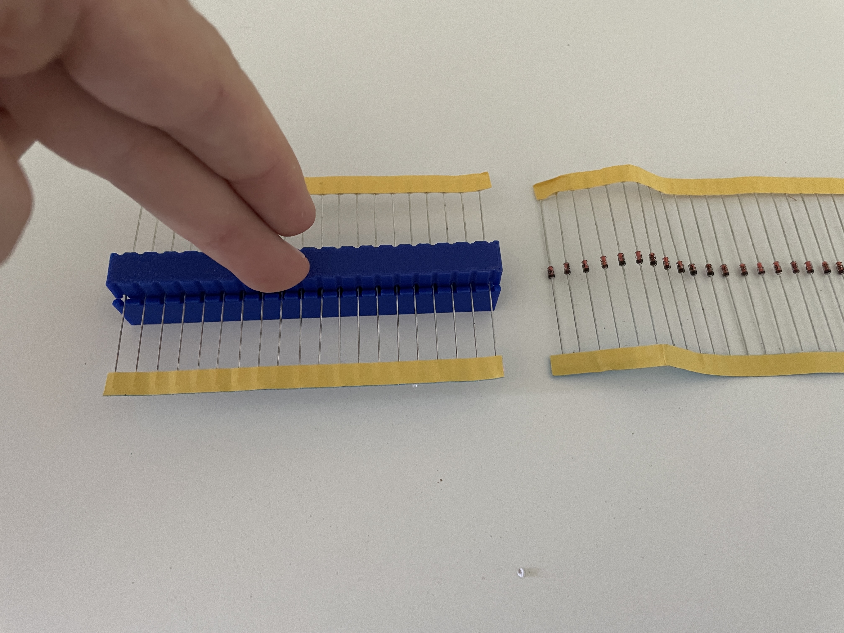
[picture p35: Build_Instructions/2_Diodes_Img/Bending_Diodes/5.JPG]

 Cut the Diode ribbon so that the you are only bending the diodes that are in the jig  <br/>

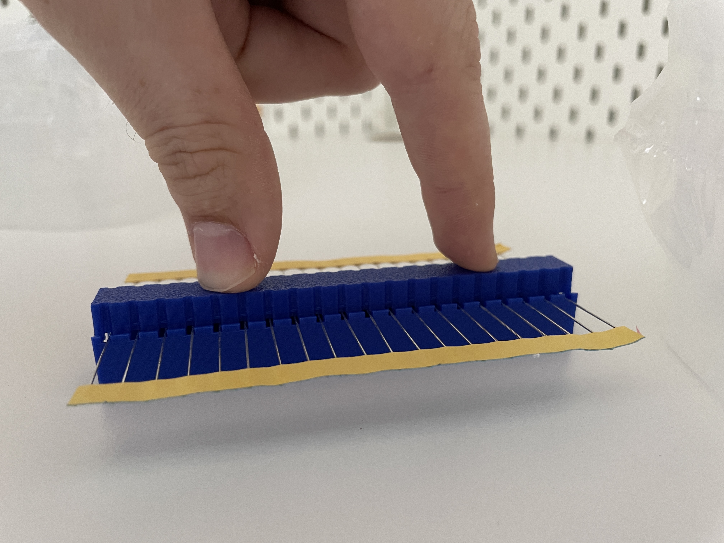
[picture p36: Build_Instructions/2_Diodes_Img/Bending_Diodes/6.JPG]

  Push down firmly on the top piece <br/>

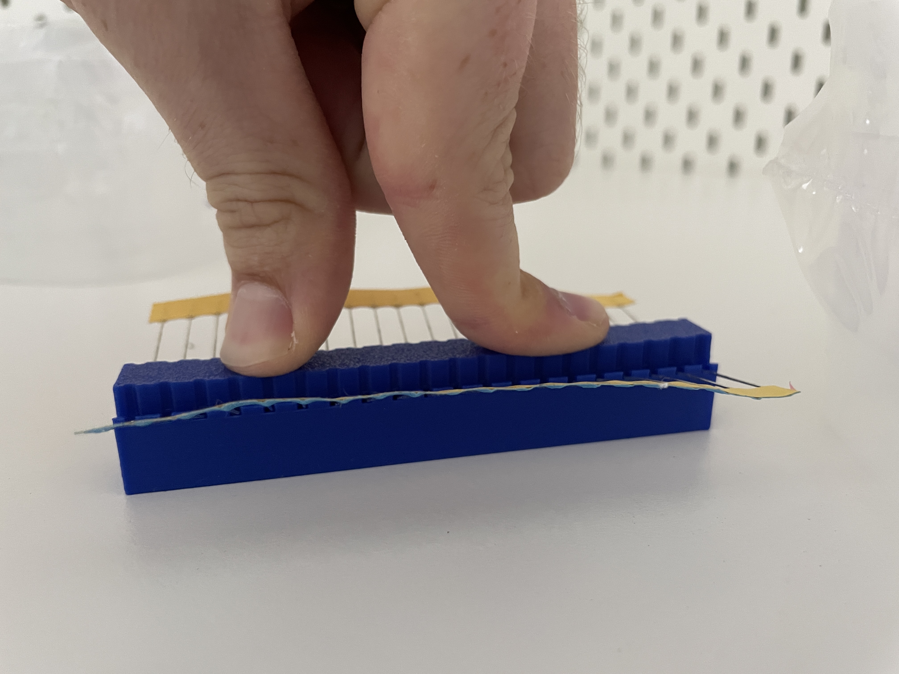
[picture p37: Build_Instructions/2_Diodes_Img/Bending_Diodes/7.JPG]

  Push down firmly on the top piece, until it looks like this <br/>

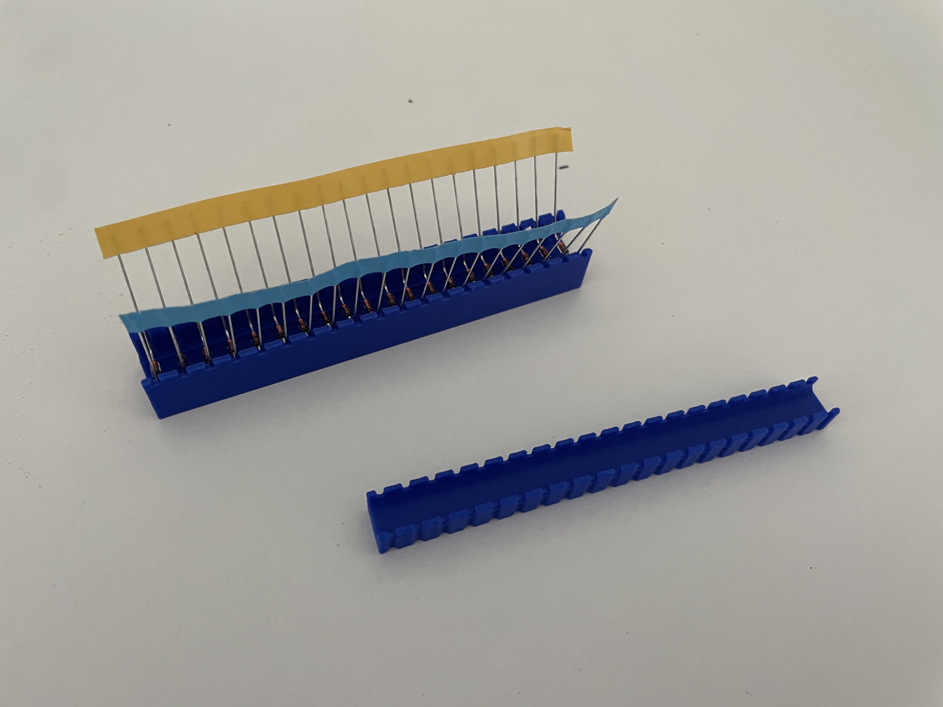
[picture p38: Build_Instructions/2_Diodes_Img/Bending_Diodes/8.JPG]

   <br/>

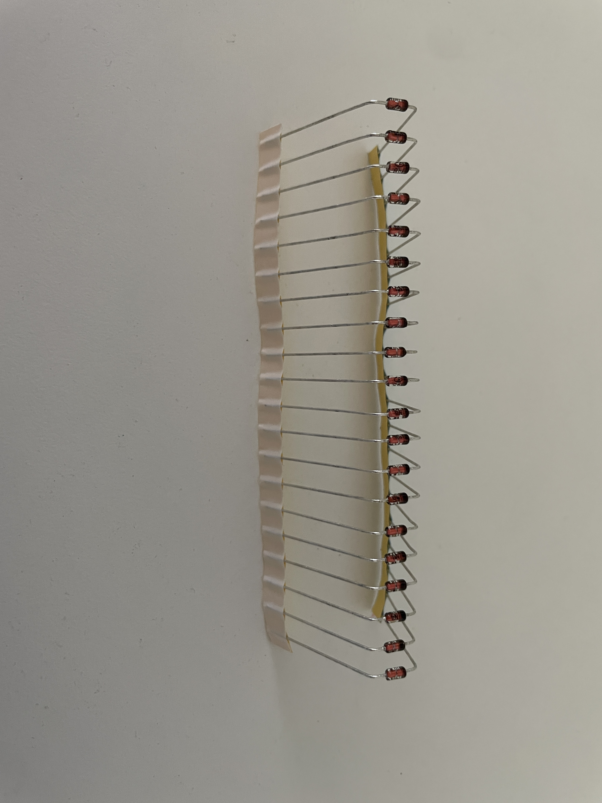
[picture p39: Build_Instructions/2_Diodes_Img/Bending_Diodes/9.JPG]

  Your diodes are now bent,Remove them, and return them to your hardware kit to not get them confused with anyone else, then bend the rest of your diodes <br/>

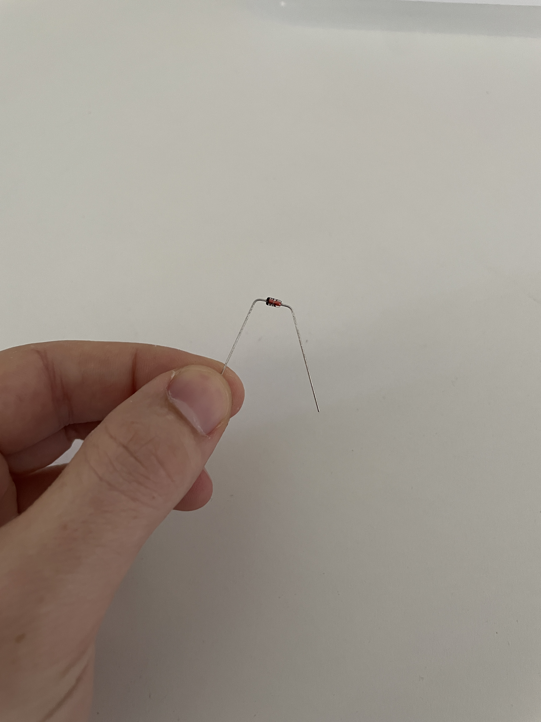
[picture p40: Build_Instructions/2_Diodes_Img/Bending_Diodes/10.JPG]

  Each Diode should look like this when removed from the paper strips,  <br/>

# Remove the Rails from the Circuit Board

Take your Circuit board from the Kit  <br/>


Remove the bubble Wrap and put it in the bin   <br/>


Notice that some parts are already soldered onto the board, near the usb port   <br/>


 And that there are RGB LEDS already soldered on the board under each switch  <br/>


 Also notice that there are "rails" on the board which I have marked in red here, These are added to help with manufacturing but must be removed to continue  <br/>

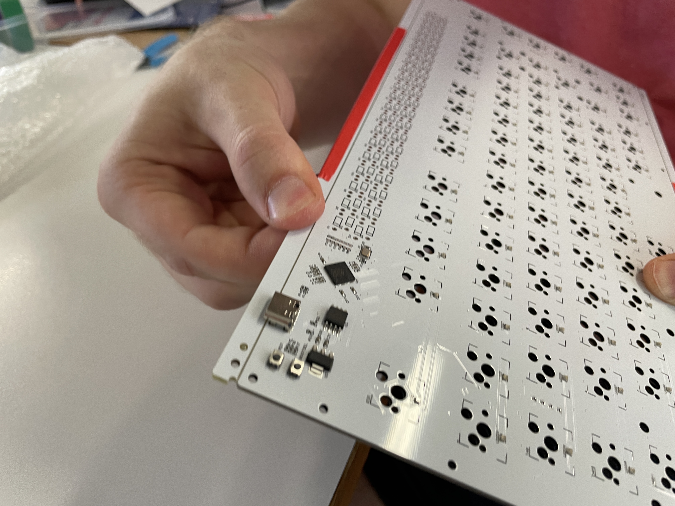
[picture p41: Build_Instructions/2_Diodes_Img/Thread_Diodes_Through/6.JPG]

 **Be VERY CAREFUL** the board is made of fiberglass and there is the potential to get fiberglass splinters if you are not careful  <br/>

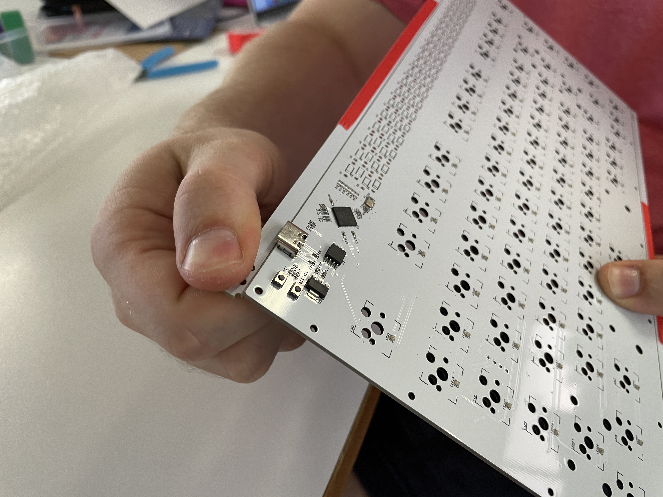
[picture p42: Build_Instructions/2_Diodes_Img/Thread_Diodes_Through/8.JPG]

 Carefully break off one corner of the rail,  <br/>

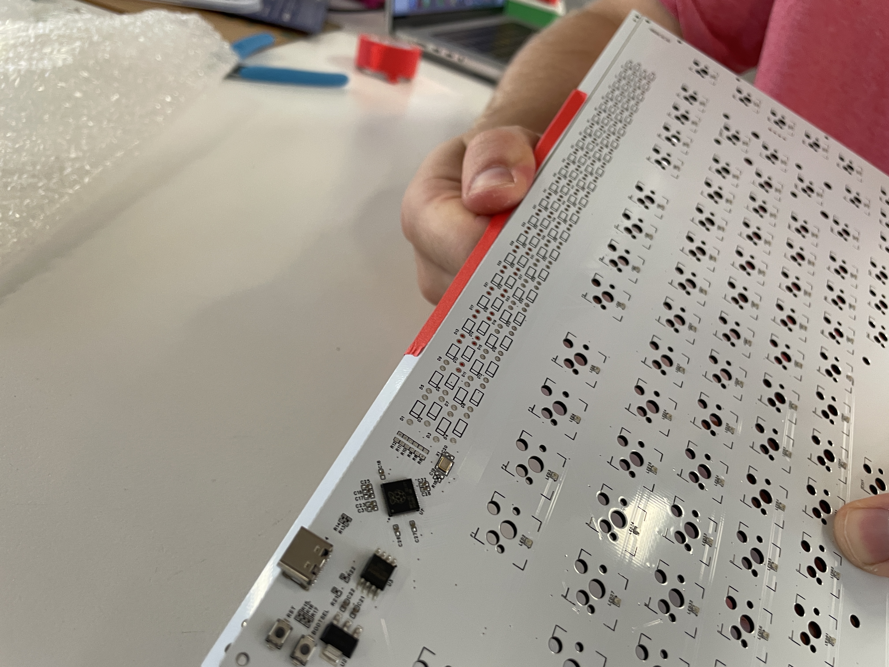
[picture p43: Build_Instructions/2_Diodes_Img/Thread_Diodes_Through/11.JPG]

 then slowly tear them off   <br/>


 Put the rails that you have just removed in the bin.   <br/>

# Thread the Diodes through the Circuit Board 

 To familiarise you with the circuit board, this image (showing the USBC port) is the TOP of the Circuit board, it is what will be faceing UP when the board is assembled,     <br/>

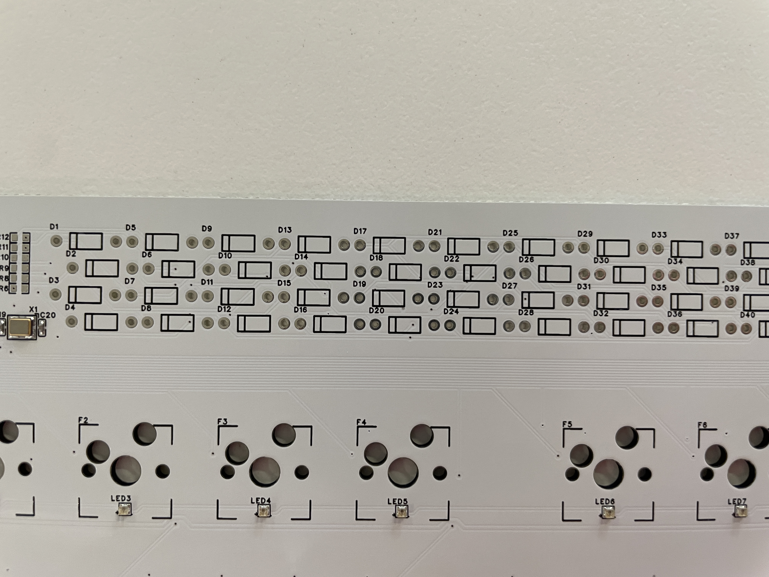
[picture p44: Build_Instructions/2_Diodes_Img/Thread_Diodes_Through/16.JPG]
 
 Notice that the TOP face of the circuit board has markings at the top edge of the board which look like diodes, AND that they have a stripe to indicate the direction to install the diodes  <br/>

  
 ### **NOTICE THE BLACK STRIPE ON THE DIODE** You will need to align this with the BLACK STRIPE on the PCB   <br/>

 
 ### **NOTICE THE BLACK STRIPE ON THE DIODE IS ALIGNED WITH THE STRIPE ON THE PCB**   <br/>

   
 The Legs of the Diode will stick through and out the other side of the PCB, 
 
 In order to make the it more comfortable, you can wedge the bag of switches from your kit under your board to "prop up" the circuit board while you install your diodes <br/>

 
 ### **Have someone else check that all of your diodes are facing the right way before you move forward, as if you solder a diode backwards the key it is wired to will not work.** <br/>

 # Tape down the Diodes
 
  Once you are happy with that all of your diodes are placed in the right way, and are centered in each opening, you will need to tape them down in order to stop them from moving when you go to solder them
  
 ### Ask for a piece of tape from a URC member running the workshop
  <br/>

 
  Make sure you press down the tape as shown so that the diodes cant move from under the tape while you solder. 
<br/>

 
  The back of your board should still look like this, with all the legs of the diodes sticking out. 
<br/>

# Soldering the Diodes

 
  Take your board to a soldering workstation, and place it face down as shown 
<br/>


  Be Safe, ensure you have a clean area to work and that it is ventilated or has an exhaust system 
<br/>


  Take your Soldering iron (hot) and first tin the tip, then bring it to your first diode

  **It is a good idea to start with the bottom row of diodes, and solder them completely, then clip the lead before moving forward to give yourself access to the next row of diodes** 
<br/>


  Place the tip of the iron on both the pad(on the pcb) and the leg of the diode, hold it there for around 3 seconds 
<br/>


  Then touch the solder to the pad, you do not need much solder, only around 1-2mm. Then quickly pull away 
<br/>


  If done correctly, the solder joint should look like a small piramid which completely covers the pad on the circuit board
<br/>

### It is ok if your first solder joints are not perfect, this is a great project because you get to do the exact same type of solder joint around 160 times, which will really help grow your skill and hopefully you notice that you get better and faster toward the end. Take your time, and ask for help if you are stuck :) 
<br/>


  Your solder joint should look like this.
<br/>


  Solder Just the bottom row of Diode legs 
<br/>


  Ask for some snippers and cut off the extra length of the legs which you have just soldered, so you will have access to the leads one row up 

  ### The cut legs will likely shoot off when snipped, make sure you and people around you are wearing eye protection
<br/>


 The snipped solder joints done need to be pretty, they just need to not be touching each other. 
<br/>


 Be careful not to connect your legs together as you can "smush" the leads together if you snip them at the same time 
<br/>


Repeat the above steps until you have soldered and snipped all of your diodes 
<br/>


Flip the board over and remove the masking tape  
<br/>

# Well Done ! You have soldered all of the Diodes for your keyboard! 

Next you will solder the Keyswitch Sockets!

# [Go to next Section](/Build_Instructions/3_Sockets.md)

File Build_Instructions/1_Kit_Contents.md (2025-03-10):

## Build your own Keyboard - URC 75

# 1. Kit Contents 

This section will show and describe all parts that come in the URC 75 kit and all of the additional tools you will require to assemble it 

Kit_Laid_out

### Your URC 75 Kit will come containing the following items:

| Image | Item |
| --- | --- |
| Kit_Laid_out  | 1x Resin 3D Printed Top Case |
| Kit_Laid_out  | 1x Resin 3d Printed Bottom Case  |
| Kit_Laid_out  | 1x Custom URC75 main circuitboard  |
| Kit_Laid_out  | 1x White Pudding style Keycaps Set  |
| Kit_Laid_out  | 1x OLED Display  |
| Kit_Laid_out  | 1x Stabilisers set ( 1x 6.25u , 3x 1.5u, Rubber gaskets, screws)  |
| Kit_Laid_out  | 84x Hotswap Sockets  |
| Kit_Laid_out  | 84x Linear Keyswitches  |
| Kit_Laid_out  |  84x Through hole Diodes |
| Kit_Laid_out  |  2x 22mm M2 Socket Head Screws |
| Kit_Laid_out  |  2x 20mm M2 Socket Head Screws |
| Kit_Laid_out  |  7x 18mm M2 Socket Head Screws |
| Kit_Laid_out  |  11x 8mm M2 Socket Head Screws |
| Kit_Laid_out  |  33x M2 Heat Set inserts |
| Kit_Laid_out  |  4x M2 Stand offs |
| Kit_Laid_out  |  1x Acryllic Window |
| Kit_Laid_out  |  1x Paper Bag Packaging |

### In addition to the URC75 kit you will need:
- Soldering Iron 
- Solder 
- M2 Allen key / driver
- Masking Tape
- Side Cutters
- **USB C Cable**

# Testing LEDs

We will download the URC75 Firmware and flash it to the board in order to test that all the presoldered LEDs function correctly before continuing

[First download the URC75 Firmwarehere](/Firmware/urc75/urc75_FIRMWARE.uf2) 

Unwrap the main circuit board and hold down the "BOOTSEL" button bear the USB C Port

Then, while holding down the "BOOTSEL" button,  plug in your Main circuit board into your computer using a known good USB C cable

The circuit board should show on your computer as a USB drive called "RP2040"

Copy the urc75_FIRMWARE.uf2 file to the this USB drive, it should self eject and reboot the circuitboard. 

The board should come to life and all LEDs on the front of the board should be lit in a rainbow pattern. 

Look over all the LEDs and ensure they are all lit, as it is easier to fix at this point rather than tearing down the whole board once it is complete. 

# [Go to Section 2](/Build_Instructions/2_Diodes.md)

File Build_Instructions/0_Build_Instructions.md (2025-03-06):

## Build your own Keyboard - URC 75

# Build Instructions

## Table of Contents 

[1. Kit Contents](/Build_Instructions/1_Kit_Contents.md)</br>
### Soldering
[2. Diodes](/Build_Instructions/2_Diodes.md)</br>
[3. Sockets](/Build_Instructions/3_Sockets.md)</br>
[4. OLED](/Build_Instructions/4_OLED.md)</br>
[5. Testing Solder Joints](/Build_Instructions/5_Testing_Solder_Joints.md)</br>
### Mechanical Assembly
[6. Heatset inserts and Case Assembly](/Build_Instructions/6_Heatset_and_Case_Assembly.md)</br>
[7. Install Switches](/Build_Instructions/7_Install_Switches.md)</br>
[8. Install Keycaps](/Build_Instructions/8_Install_Keycaps.md)</br>
### Firmware Install
[9. Install Firmware](/Build_Instructions/9_Install_Firmware.md)</br>

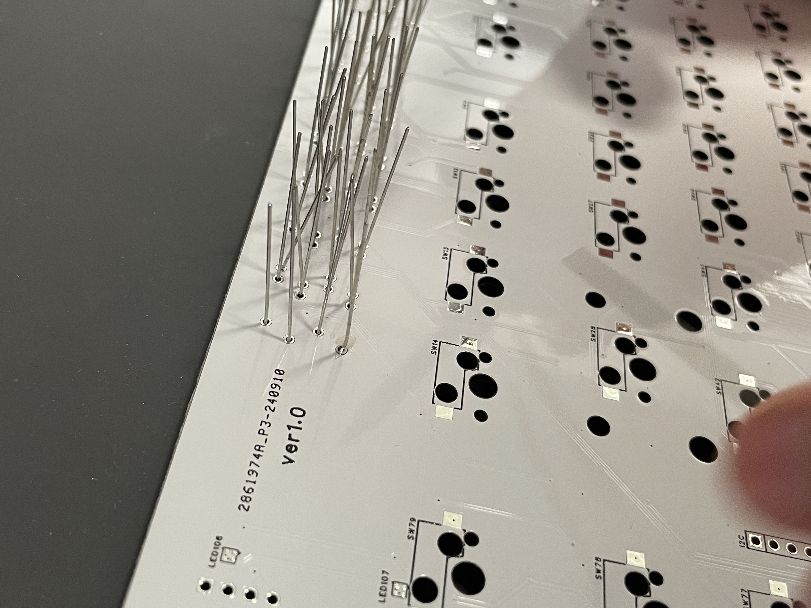
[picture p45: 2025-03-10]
Build_Instructions/2_Diodes_Img/Solder the Diodes/7.JPG

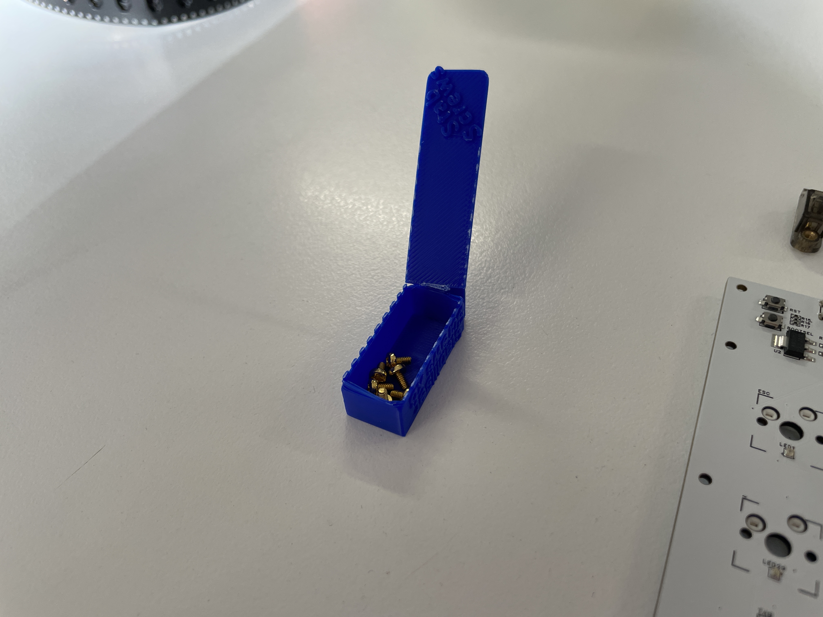
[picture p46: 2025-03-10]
Build_Instructions/6_Heatsets_Case_img/Add the Stabilisers/6.JPG

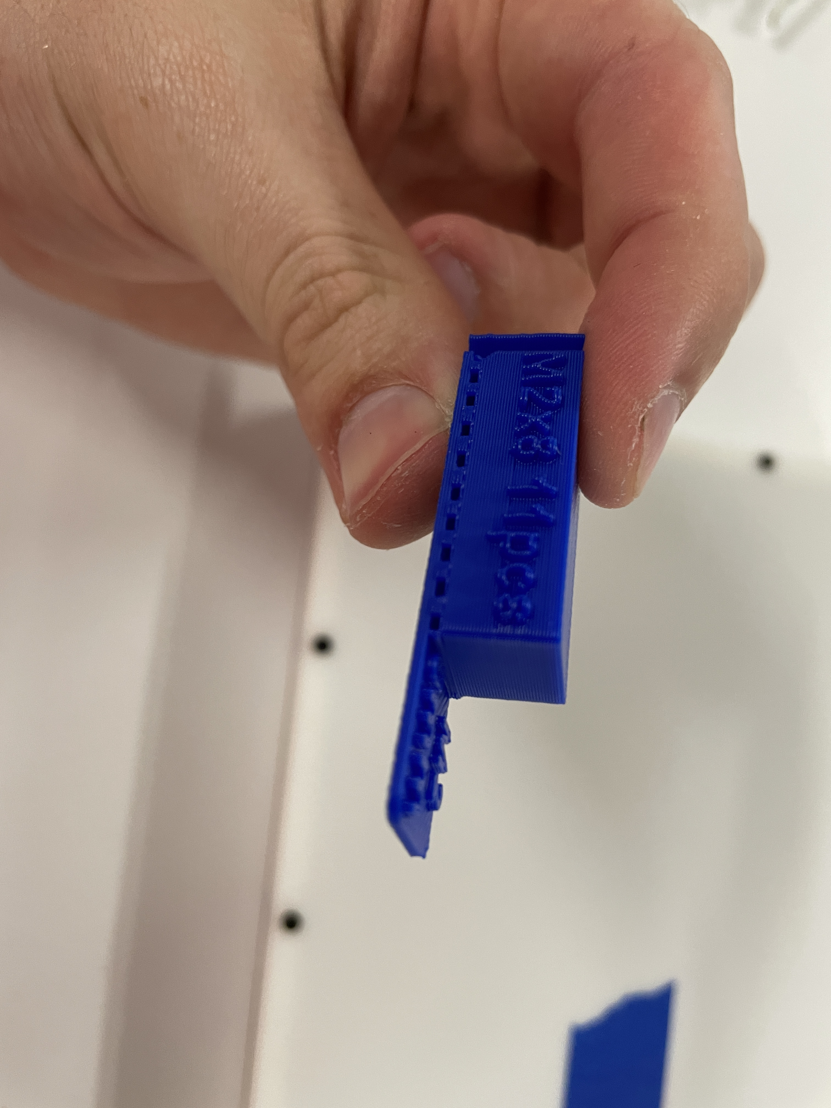
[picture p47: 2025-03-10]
Build_Instructions/6_Heatsets_Case_img/Add Top Case and Screw from bottom/12.JPG

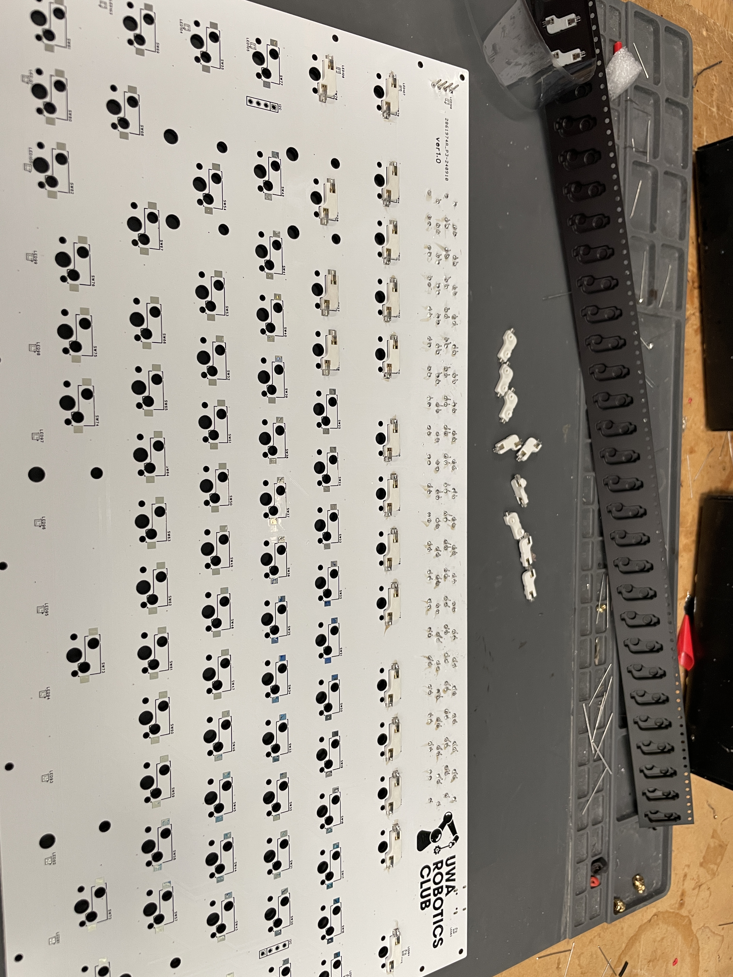
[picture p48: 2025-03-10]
Build_Instructions/3_Sockets_img/Solder the Sockets/8.JPG

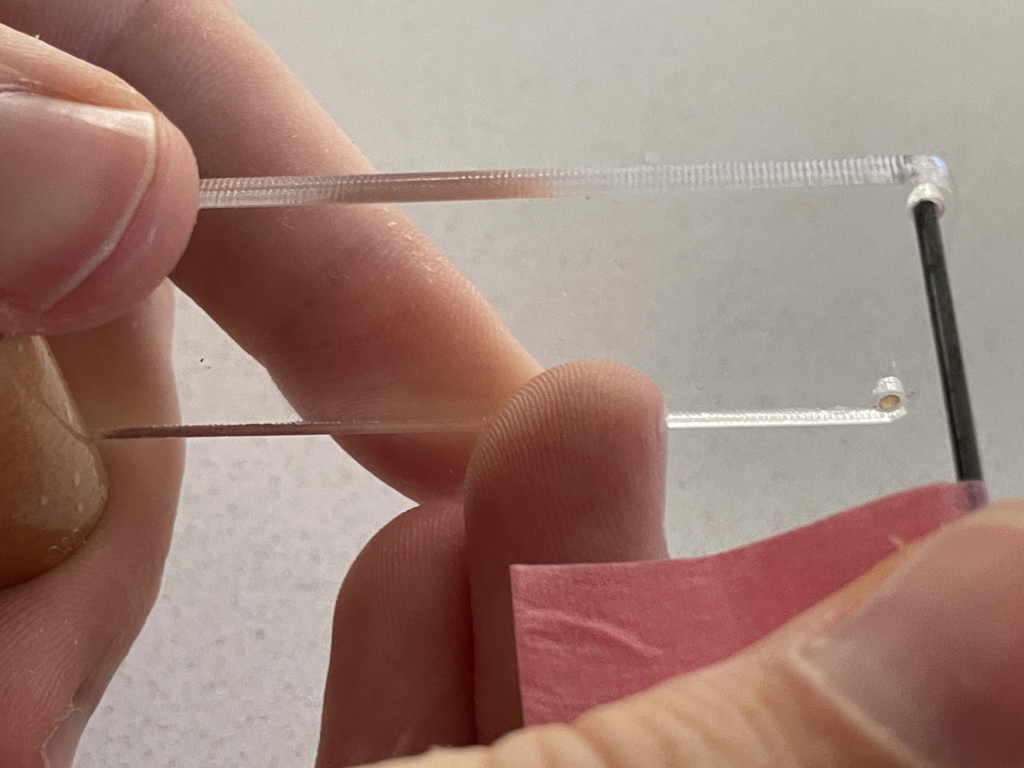
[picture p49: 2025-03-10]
Build_Instructions/6_Heatsets_Case_img/Add the Acrylic Windows/6.JPG

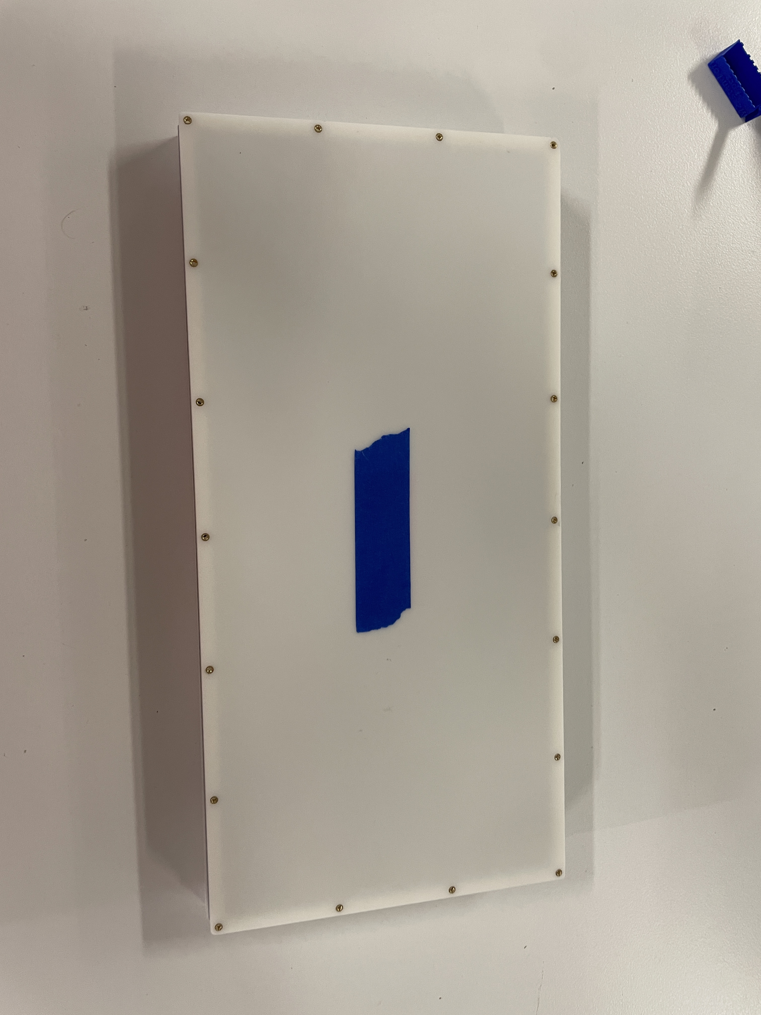
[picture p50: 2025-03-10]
Build_Instructions/6_Heatsets_Case_img/Add Top Case and Screw from bottom/3.JPG

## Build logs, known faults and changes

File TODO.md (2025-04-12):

# Repository To Do List 

## Immediate Actions - High Priority 
- Complete the Build instructions to a "v1" Level 
    - ~~0 Build Instructions Home page~~
    - ~~1 Kit Contents Page~~
    - ~~2 Diodes~~
    - ~~3 Sockets~~
    - ~~4 OLED~~
    - ~~5 Testing solder Joints~~
    - 6 Heat Set inserts and Case Assembly
    - 7 Install Keyswitches 
    - 8 Install Keycaps 
    - 9 Install Firmware 

- Rebuild the firmware with 1 more LED so they all light up

- Add Warnings and improve the Build instructions in the following ways 
    - Show how to use bubble wrap when soldering to prevent damage to your board 
    - Improve the Testing instructions and visualisations 
    
- Add the hardware Files to the repo 

- Gather main issues and create a "support and troubleshooting" page 
    - LED has come off 
    - Cold solder joints 
    - How to troubleshoot faulty keys 
    - Warped Cases 
    - 

## Longer Term Goals 

- Video tutorial of how to assemble your keyboard

- Use Github actions to make it easy to build an modify your firmware. 

- Build a testing program so we are not reliant on the QMK testing site 

- Show examples on how to customise your keyboard 
    - Print a new case in a new colour 
    - Rebuild the firmware 
        - new animation 
        - New keymap
        - change the 4 user keys to another function

- Write a "lessons learned" page with information on what design choices we would change for a "version 2" 
    - More modularity in the Design 
    - More testing ahead of time 
    - More focus on the tracking costs 
    - Think from the customers perspective
    - have the github ready ahead of the launch of the product 
    - Buy an extra 5-10% of each component for failure redundancy and spares 
    - have a clear policy on repairs and support from the start 
    - Try to improve the marketing to make the product more understandable

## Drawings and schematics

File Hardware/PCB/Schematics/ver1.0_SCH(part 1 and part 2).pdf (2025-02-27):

RP2040

## Raspberry Pi

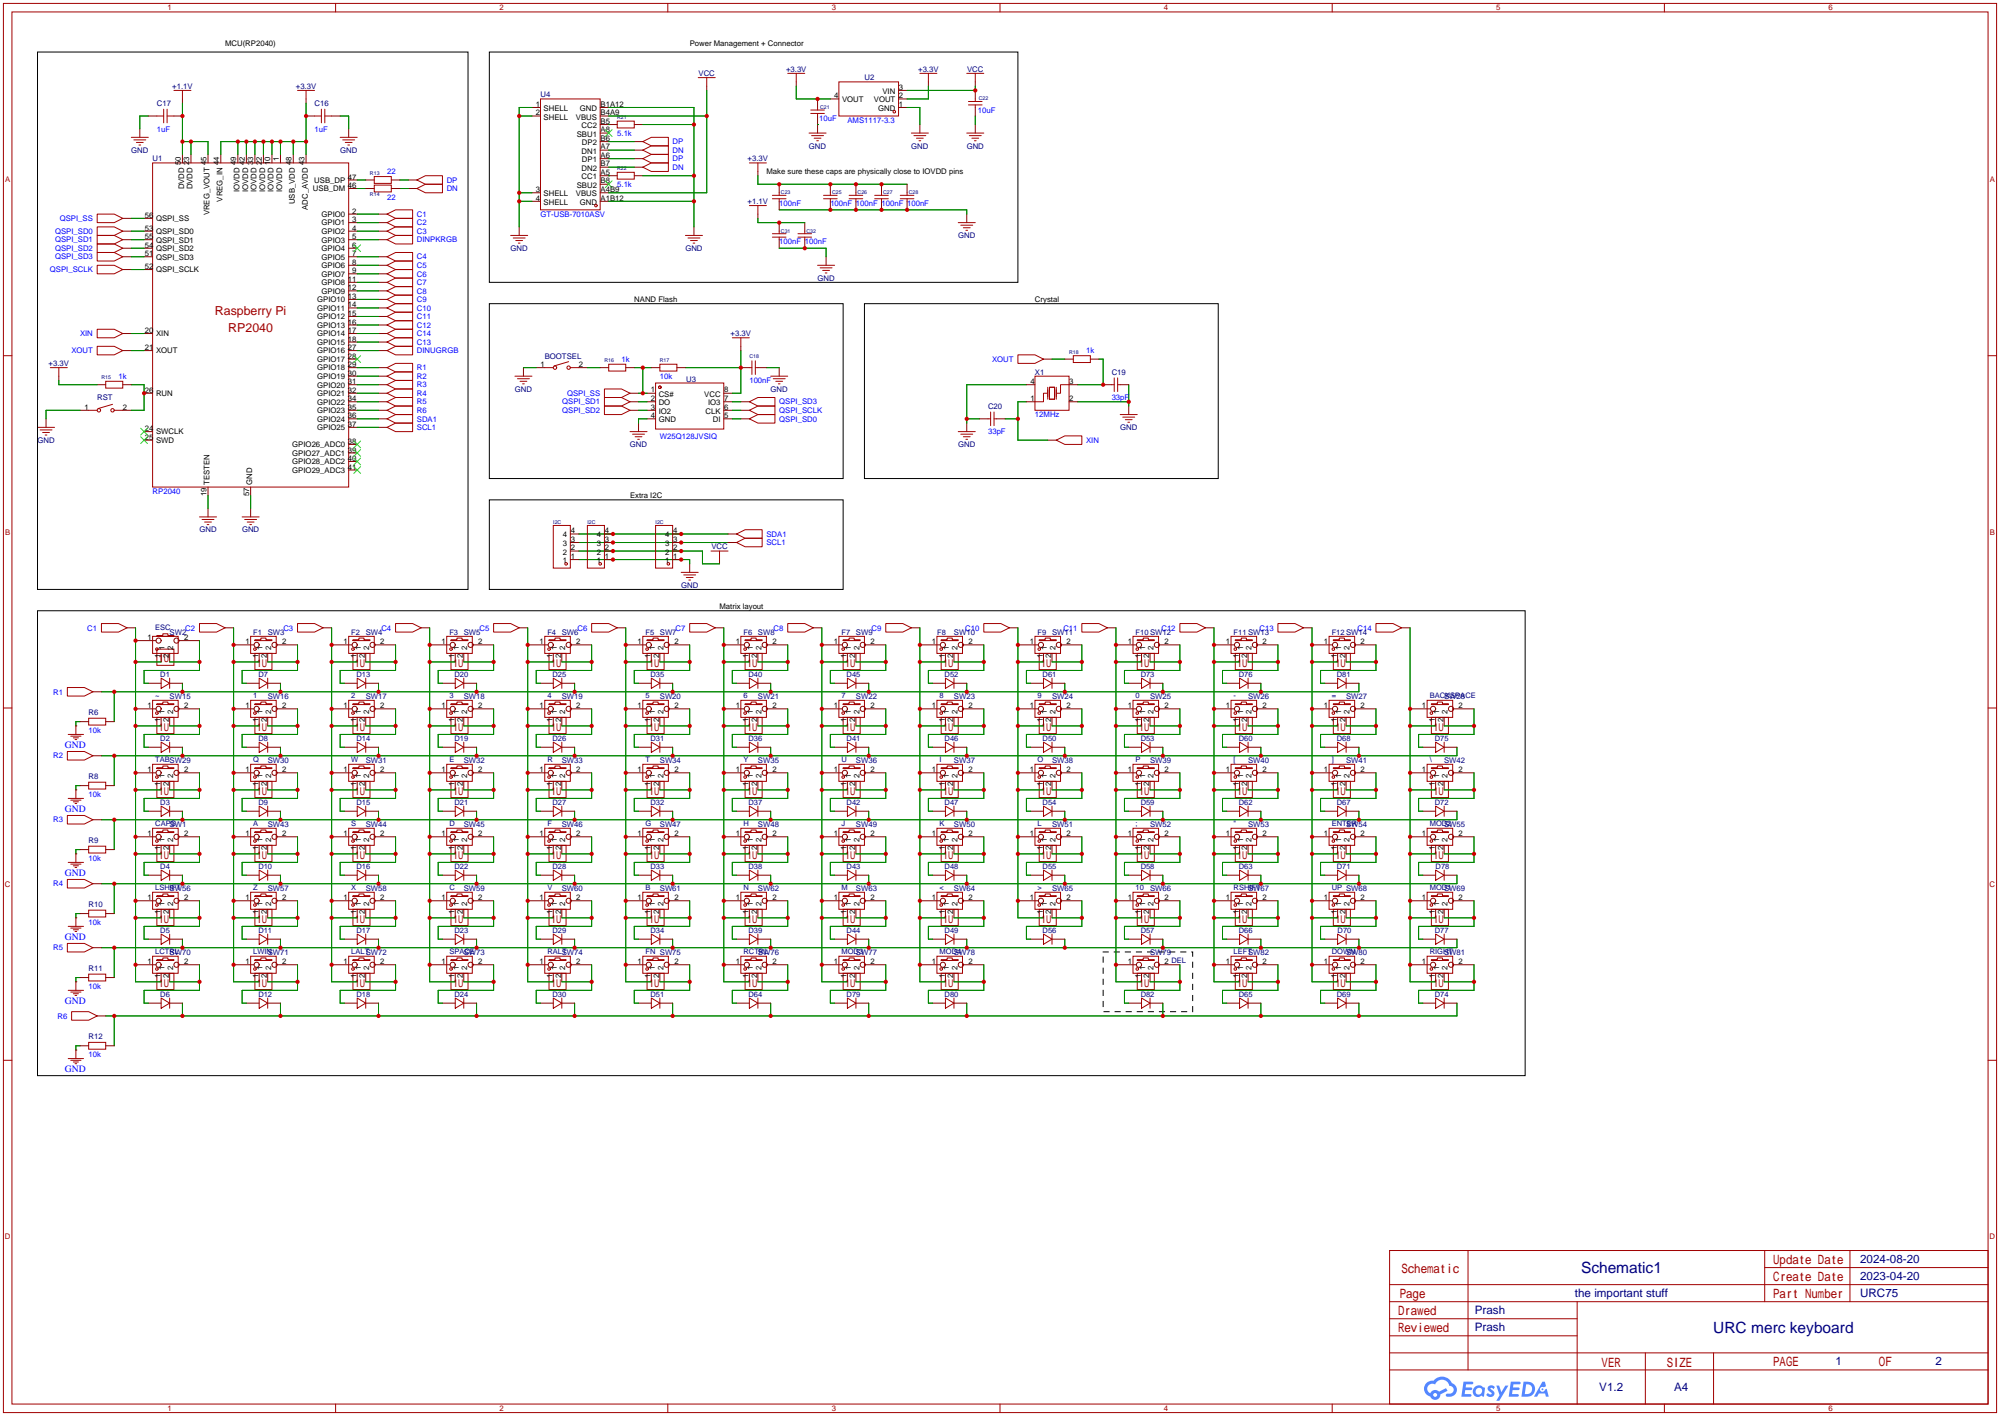
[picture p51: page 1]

Make sure these caps are physically close to IOVDD pins

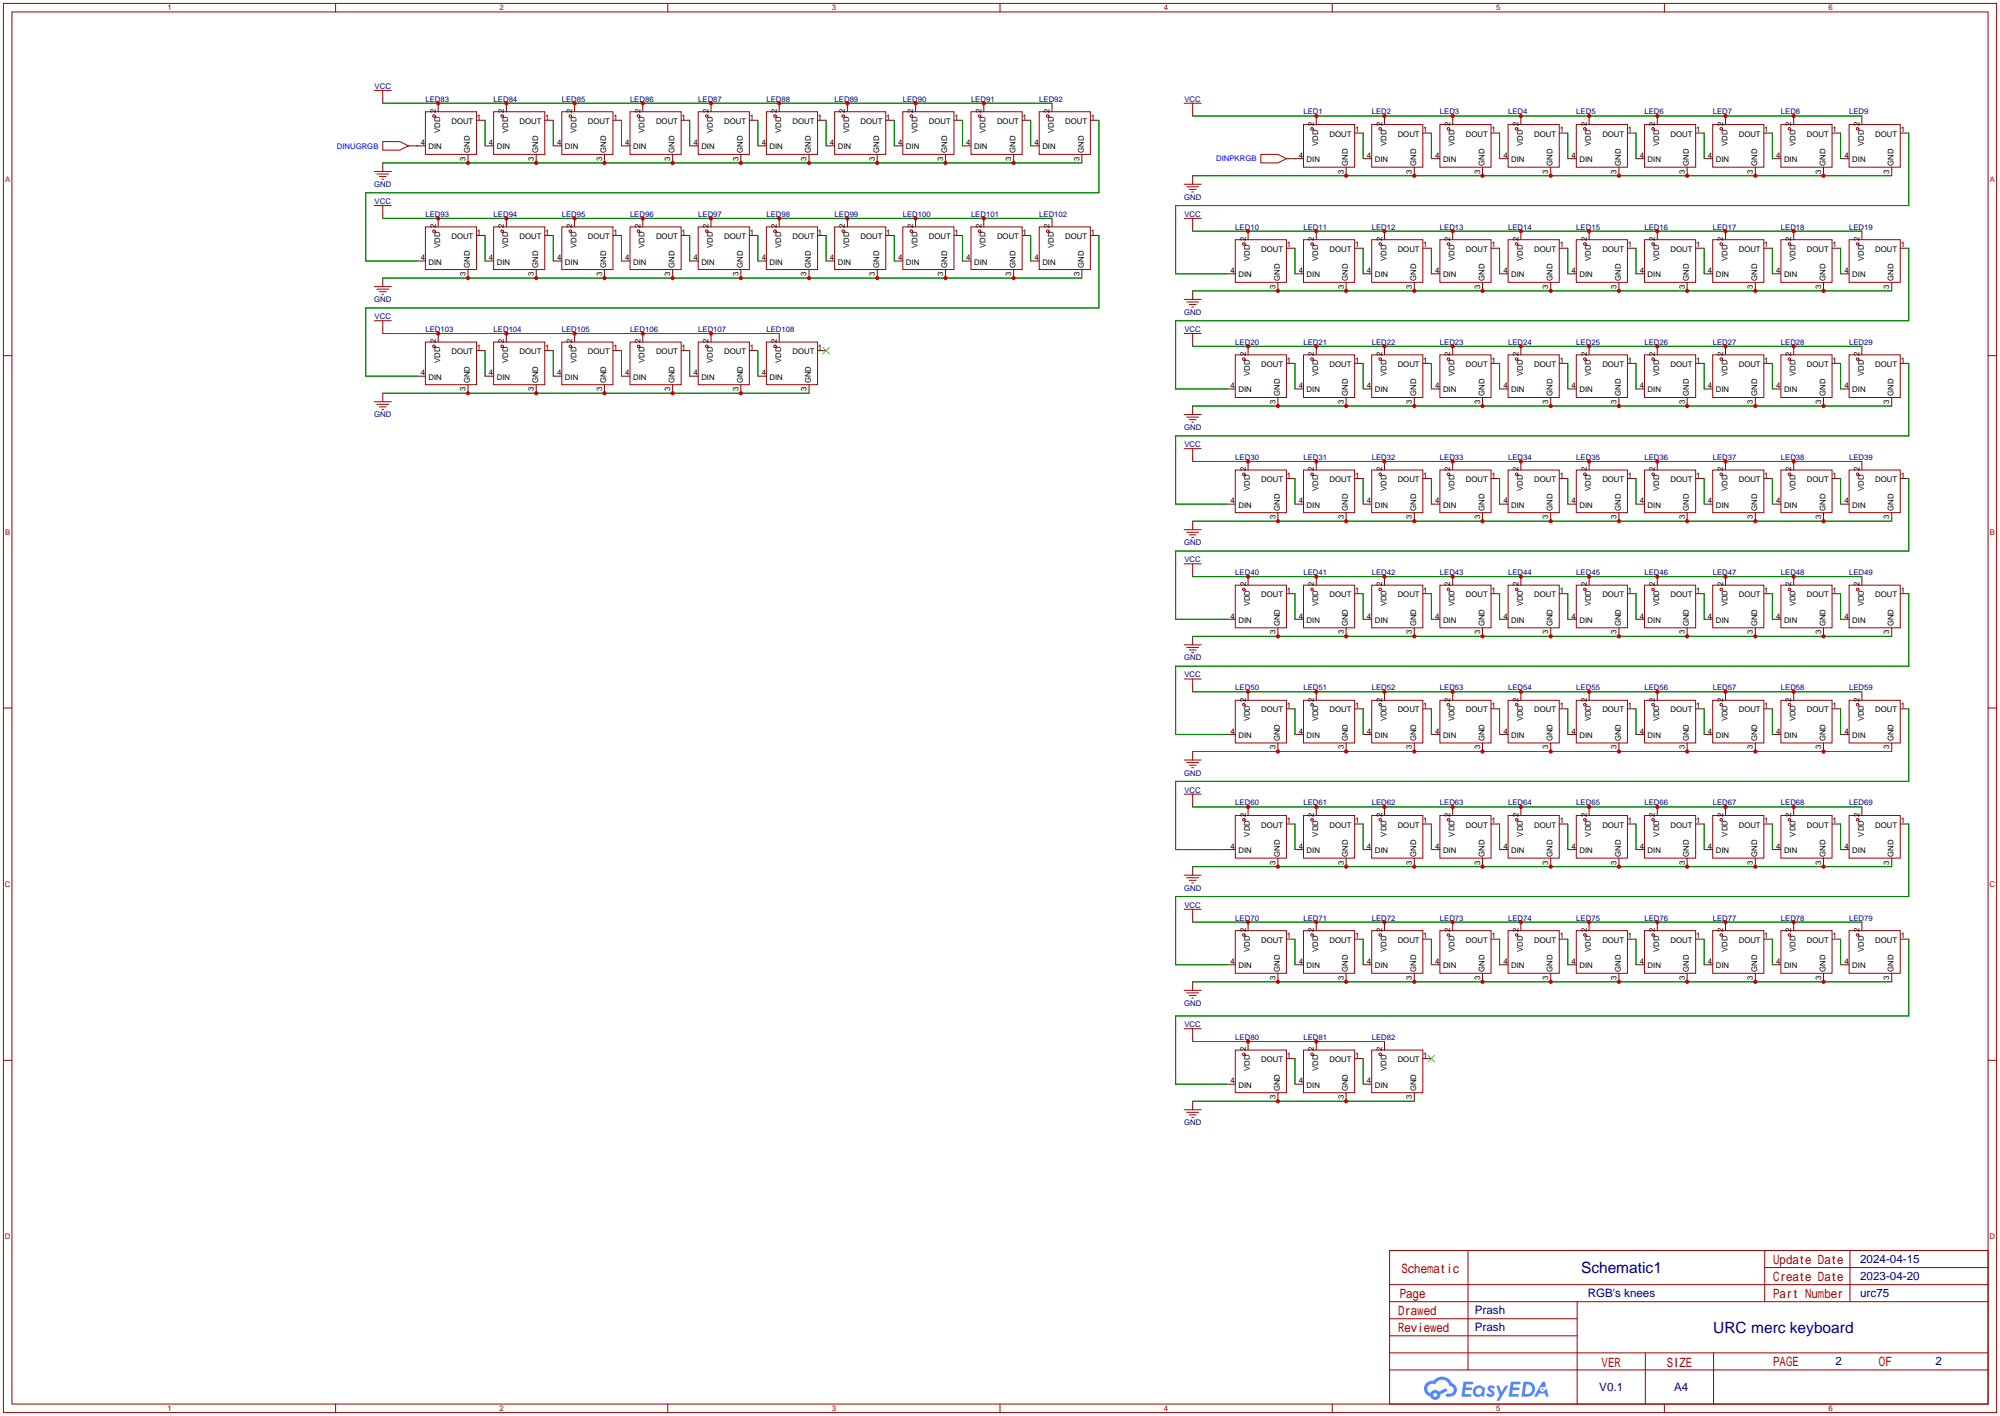
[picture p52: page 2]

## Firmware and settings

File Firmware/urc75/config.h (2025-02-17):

// Copyright 2023 quarterpie
// SPDX-License-Identifier: GPL-2.0-or-later
#pragma once

/* Key matrix size */
#define MATRIX_ROWS 6
#define MATRIX_COLS 14

/* Key matrix pins */
#define MATRIX_ROW_PINS { GP18, GP19, GP20, GP21, GP22, GP23 }
#define MATRIX_COL_PINS { GP0, GP1, GP2, GP5, GP6, GP7, GP8, GP9, GP10, GP11, GP12, GP13, GP15, GP14 }

/* OLED configuration */
#define OLED_DISPLAY_128X32s
#define I2C_DRIVER I2CD0
#define I2C1_SCL_PIN GP25
#define I2C1_SDA_PIN GP24
#define OLED_TIMEOUT 30000

// Debounce 
#define DEBOUNCE 5

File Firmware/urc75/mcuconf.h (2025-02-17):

/*
    ChibiOS - Copyright (C) 2006..2021 Giovanni Di Sirio

    Licensed under the Apache License, Version 2.0 (the "License");
    you may not use this file except in compliance with the License.
    You may obtain a copy of the License at

        http://www.apache.org/licenses/LICENSE-2.0

    Unless required by applicable law or agreed to in writing, software
    distributed under the License is distributed on an "AS IS" BASIS,
    WITHOUT WARRANTIES OR CONDITIONS OF ANY KIND, either express or implied.
    See the License for the specific language governing permissions and
    limitations under the License.
*/

#ifndef MCUCONF_H
#define MCUCONF_H

/*
 * RP2040_MCUCONF drivers configuration.
 *
 * IRQ priorities:
 * 3...0        Lowest...Highest.
 *
 * DMA priorities:
 * 0...1        Lowest...Highest.
 */

#define RP2040_MCUCONF

/*
 * HAL driver system settings.
 */
#define RP_NO_INIT                          FALSE
#define RP_CORE1_START                      FALSE
#define RP_CORE1_VECTORS_TABLE              _vectors
#define RP_CORE1_ENTRY_POINT                _crt0_c1_entry
#define RP_CORE1_STACK_END                  __c1_main_stack_end__

/*
 * IRQ system settings.
 */
#define RP_IRQ_SYSTICK_PRIORITY             2
#define RP_IRQ_TIMER_ALARM0_PRIORITY        2
#define RP_IRQ_TIMER_ALARM1_PRIORITY        2
#define RP_IRQ_TIMER_ALARM2_PRIORITY        2
#define RP_IRQ_TIMER_ALARM3_PRIORITY        2
#define RP_IRQ_ADC1_PRIORITY                3
#define RP_IRQ_UART0_PRIORITY               3
#define RP_IRQ_UART1_PRIORITY               3
#define RP_IRQ_SPI0_PRIORITY                2
#define RP_IRQ_SPI1_PRIORITY                2
#define RP_IRQ_USB0_PRIORITY                3
#define RP_IRQ_I2C0_PRIORITY                2
#define RP_IRQ_I2C1_PRIORITY                2
#define RP_IRQ_RTC_PRIORITY                 3

/*
 * ADC driver system settings.
 */
#define RP_ADC_USE_ADC1                     FALSE

/*
 * SIO driver system settings.
 */
#define RP_SIO_USE_UART0                    FALSE
#define RP_SIO_USE_UART1                    FALSE

/*
 * SPI driver system settings.
 */
#define RP_SPI_USE_SPI0                     FALSE
#define RP_SPI_USE_SPI1                     FALSE
#define RP_SPI_SPI0_RX_DMA_CHANNEL          RP_DMA_CHANNEL_ID_ANY
#define RP_SPI_SPI0_TX_DMA_CHANNEL          RP_DMA_CHANNEL_ID_ANY
#define RP_SPI_SPI1_RX_DMA_CHANNEL          RP_DMA_CHANNEL_ID_ANY
#define RP_SPI_SPI1_TX_DMA_CHANNEL          RP_DMA_CHANNEL_ID_ANY
#define RP_SPI_SPI0_DMA_PRIORITY            1
#define RP_SPI_SPI1_DMA_PRIORITY            1
#define RP_SPI_DMA_ERROR_HOOK(spip)

/*
 * PWM driver system settings.
 */
#define RP_PWM_USE_PWM0                     FALSE
#define RP_PWM_USE_PWM1                     FALSE
#define RP_PWM_USE_PWM2                     FALSE
#define RP_PWM_USE_PWM3                     FALSE
#define RP_PWM_USE_PWM4                     FALSE
#define RP_PWM_USE_PWM5                     FALSE
#define RP_PWM_USE_PWM6                     FALSE
#define RP_PWM_USE_PWM7                     FALSE
#define RP_PWM_IRQ_WRAP_NUMBER_PRIORITY     3

/*
 * I2C driver system settings.
 */
#define RP_I2C_USE_I2C0                     TRUE
#define RP_I2C_USE_I2C1                     FALSE
#define RP_I2C_BUSY_TIMEOUT                 50
#define RP_I2C_ADDRESS_MODE_10BIT           FALSE

/*
 * USB driver system settings.
 */
#define RP_USB_USE_USBD0                    TRUE
#define RP_USB_FORCE_VBUS_DETECT            TRUE
#define RP_USE_EXTERNAL_VBUS_DETECT         FALSE
#define RP_USB_USE_ERROR_DATA_SEQ_INTR      FALSE

#endif /* MCUCONF_H */

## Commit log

2024-03-19 init hardware files
    [Drill_NPTH_Through.DRL, Drill_PTH_Through.DRL, Drill_PTH_Through_Via.DRL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]
2024-03-19 init mechanical design files
    [Acrylic bottom.iges, Acrylic window.iges, Bottom Cap.iges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]
2025-02-27 Updated hardware information
    [1_P1.schdoc, 1_the important stuff.schdoc, 2_RGB's knees.schdoc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]
2025-03-10 added diode instruction manual section
2025-03-10 update to sockets
2025-03-11 updating and adding the sockets build instructions

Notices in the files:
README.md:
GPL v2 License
